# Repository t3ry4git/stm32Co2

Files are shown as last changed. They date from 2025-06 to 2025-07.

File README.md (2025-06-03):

# stm32Co2

A simple CO2 and environmental monitor based on the STM32F103C8 microcontroller. The firmware reads temperature and humidity from a DHT22 sensor, measures CO2 concentration using an MHZ19B module and displays values on an SSD1306 OLED screen.

## Hardware requirements

- **MCU:** STM32F103C8 ("Blue Pill" or compatible)
- **Temperature/Humidity sensor:** DHT22
- **CO2 sensor:** MHZ19B (UART interface)
- **Display:** SSD1306 I2C OLED

## Building with STM32CubeIDE

1. Open the `test.ioc` project file in STM32CubeIDE.
2. Let CubeIDE generate the project files if prompted.
3. Build the `test` target from the IDE. Default settings produce both `Debug` and `Release` outputs.
4. Flash the resulting binary to your board using the built‑in CubeIDE programmer or an external tool such as ST‑Link.

## Third‑party software

This repository includes STM32 HAL drivers from STMicroelectronics under the BSD‑3‑Clause license as found in `Drivers/STM32F1xx_HAL_Driver/LICENSE.txt`. The SSD1306 display driver and font code in `Core/Src` and `Core/Inc` are distributed under the GNU GPL version 3.

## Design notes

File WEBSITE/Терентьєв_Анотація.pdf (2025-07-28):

2

АНОТАЦІЯ
Кваліфікаційна робота включає пояснювальну записку (65- с., 24 - рис. 2 -

табл., 3- додатки).

У роботі розроблено портативну систему для моніторингу температури,

відносної вологості та концентрації вуглекислого газу у повітрі закритих

приміщень. Апаратна частина побудована на мікроконтролері STM32F103C8T6

з підключенням цифрових сенсорів DHT22 та MH-Z19B. Перший забезпечує

вимірювання температури й вологості, другий — контроль рівня вуглекислого

газу на основі недисперсної інфрачервоної технології (NDIR).

У процесі реалізації:

― | Проведено аналіз існуючих технічних рішень у сфері локального моніторингу повітряного середовища;
― | Визначено вимоги до портативної системи з урахуванням умов експлуатації;
― | Розроблено принципову електричну схему пристрою та підібрано відповідні компоненти;
― | Реалізовано прошивку для мікроконтролера з функціями зчитування, обробки та виведення даних на графічний дисплей.

Розроблена система характеризується низьким енергоспоживанням,

компактними розмірами та може функціонувати автономно від стаціонарних

джерел живлення. Такий пристрій є доцільним для застосування у житлових,

навчальних, офісних або лабораторних приміщеннях, де необхідно контролювати

стан повітряного середовища.

Ключові слова: STM32, MH-Z19B, DHT22, моніторинг, CO2, температура,

вологість, NDIR, портативна система, мікроконтролер.

3

ABSTRACT

The qualification work includes an explanatory note (65 p.,24 figures,2 tables,3

appendices).

This work presents the development of a portable system for monitoring

temperature, relative humidity, and carbon dioxide concentration in indoor

environments. The hardware is based on the STM32F103C8T6 microcontroller, with

connected digital sensors DHT22 and MH-Z19B. The DHT22 measures temperature

and humidity, while the MH-Z19B provides carbon dioxide concentration data using

non-dispersive infrared (NDIR) technology.

During the development process:

― | Existing technical solutions for local air quality monitoring were analyzed;
― | System requirements were defined according to operating conditions;
― | A circuit diagram was developed and appropriate components selected;
― | Firmware was implemented to enable data acquisition, processing, and display on a graphical screen.

The system is characterized by low power consumption, compact dimensions,

and the ability to operate independently of stationary power sources. It is suitable for

use in residential, educational, office, or laboratory environments where air quality

monitoring is required.

Keywords: STM32, MH-Z19B, DHT22, monitoring, CO2, temperature,

humidity, NDIR, portable system, microcontroller.

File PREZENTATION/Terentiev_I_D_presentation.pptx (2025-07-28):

## Портативна система моніторингу концентрації CO2 з графічним інтерфейсом

Виконав: студент IV курсу, групи КВ-11
Терентьєв Іван Дмитрович
Керівник: доц.каф. СПіСКС, к.т.н.
Щербина Олександр Андрійович

## Актуальність

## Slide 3

Погіршення якості повітря у приміщеннях

Згідно з дослідженнями, підвищений рівень CO₂ безпосередньо впливає на працездатність, викликає втому, сонливість та знижує концентрацію. У більшості житлових і робочих приміщень відсутні засоби моніторингу цього параметра.

Недоступність ефективних автономних рішень

Існуючі пристрої для контролю мікроклімату здебільшого дорогі, потребують постійного живлення або мають складну структуру налаштувань, що обмежує їх використання у побуті чи в умовах обмежених ресурсів.

Потреба у мобільних та енергоефективних системах

Більшість доступних рішень або складні в користуванні, або прив’язані до хмарних сервісів. Це унеможливлює їх застосування у простих побутових умовах, де потрібна швидка та надійна індикація якості повітря.

## Мета

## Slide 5

Забезпечити контроль якості повітря у приміщеннях. Розробити портативний пристрій для моніторингу CO₂, температури та вологості, що допоможе оперативно реагувати на зміни мікроклімату.
Підвищити комфорт і продуктивність. Створити технічне рішення, що сприятиме кращому самопочуттю людей у навчальних, житлових і робочих просторах.
Реалізувати автономну систему. Забезпечити енергонезалежність пристрою за допомогою живлення від акумулятора та оптимального енергоспоживання.
Використати сучасну елементну базу. Застосувати мікроконтролер STM32 та цифрові сенсори для точних і стабільних вимірювань без потреби в складному обслуговуванні.

## Огляд існуючих рішень

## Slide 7

Смарт-термостати

Google Nest, Tado — керують опаленням, збирають дані про температуру, вологість і рух. Вимагають підключення до Wi-Fi.

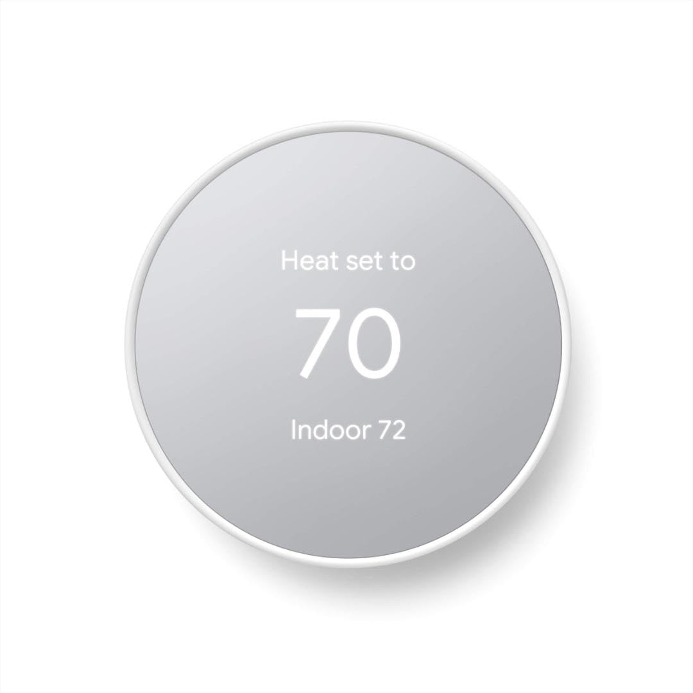
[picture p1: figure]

Компактні метеостанції

Netatmo, Xiaomi Mi Monitor — вимірюють базові параметри (температура, вологість), мають E-Ink дисплеї, працюють на батарейках.

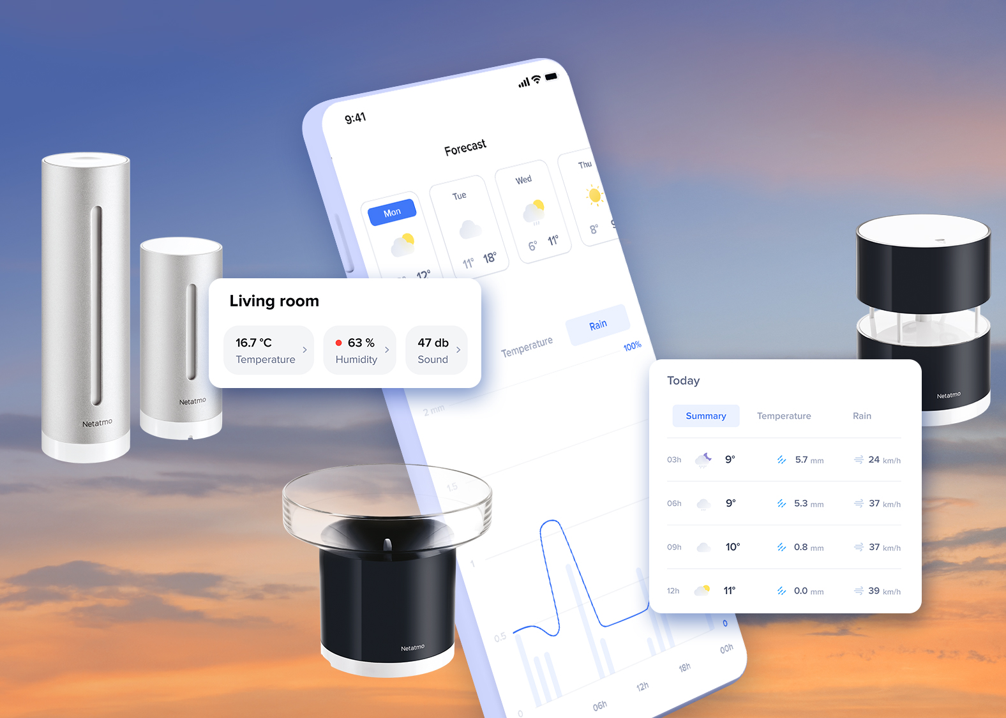
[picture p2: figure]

Системи безпеки з кліматичним моніторингом

Ajax LifeQuality — поєднують CO₂-датчики з охоронними функціями. Працюють у складі фірмової екосистеми.

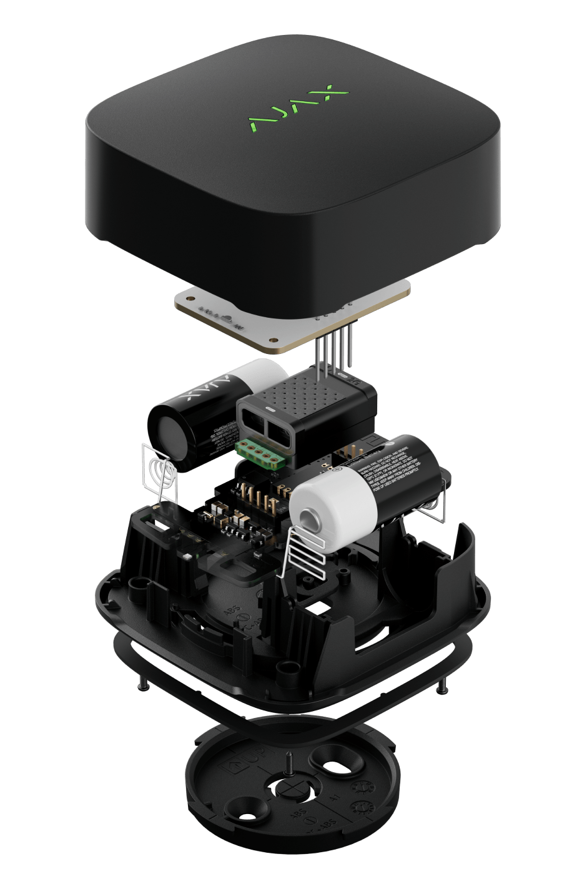
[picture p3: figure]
Ajax LifeQuality is a smart air quality monitor

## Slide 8

Професійні вимірювачі

Testo, ELT Sensor — призначені для лабораторій. Забезпечують точні вимірювання CO₂, TVOC, температури. Дорогі, потребують калібрування.

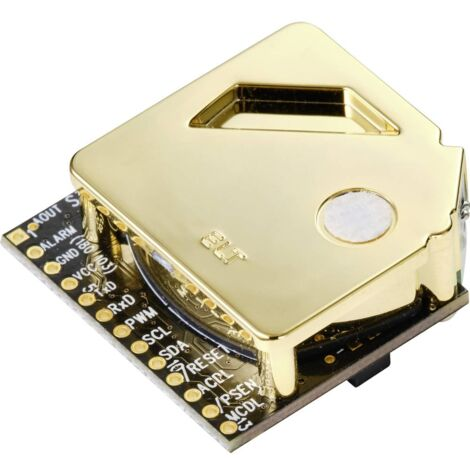
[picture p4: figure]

DIY-рішення загального призначення

Конструкції на базі Arduino, ESP або STM32. Підходять для ентузіастів, гнучкі, але потребують знань у схемотехніці та програмуванні.

Системи з інтегрованим моніторингом

Dyson, Mitsubishi Electric — мають вбудовані сенсори повітря в системах вентиляції або кондиціювання. Висока ціна, обмежена модифікація.

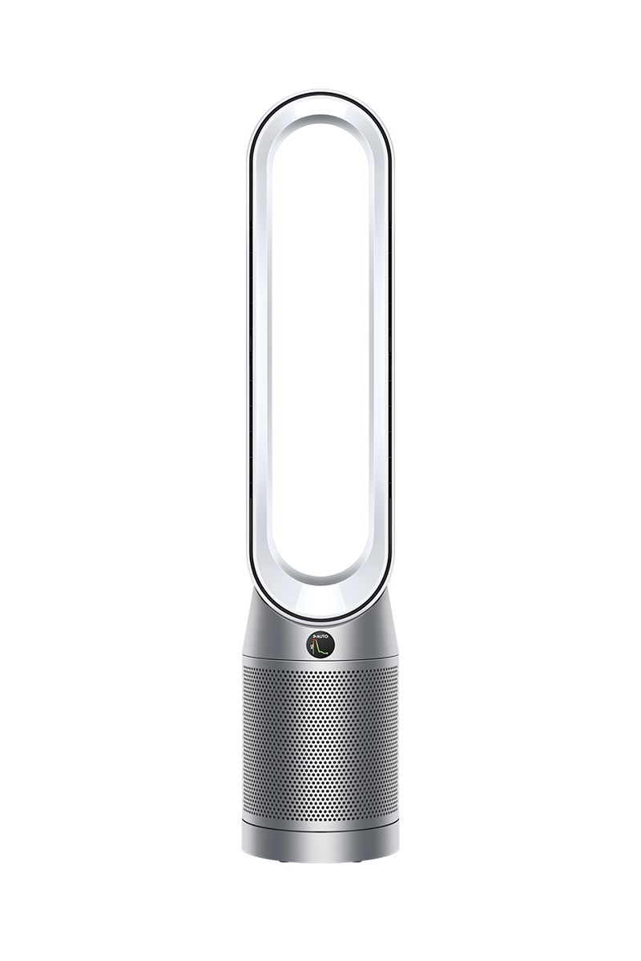
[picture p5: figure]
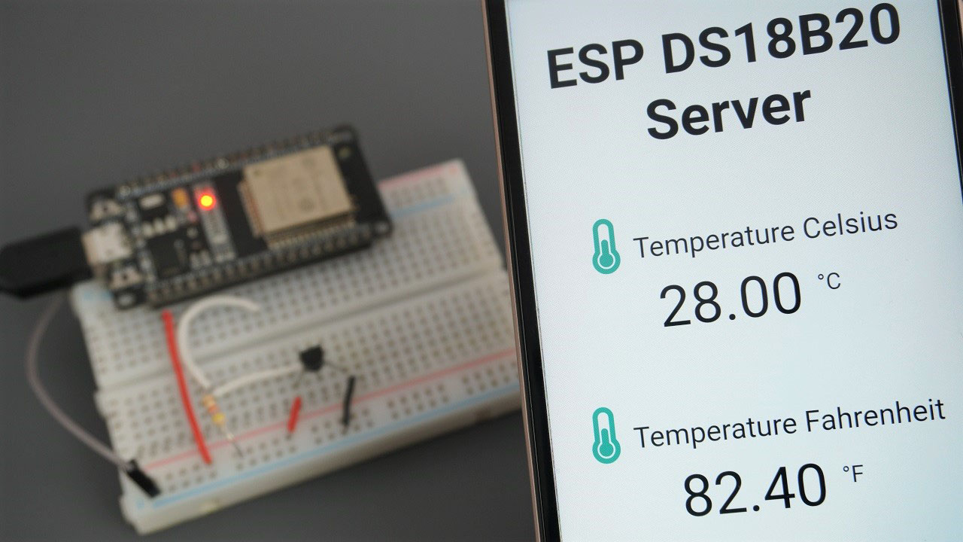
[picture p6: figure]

## Обрані технології

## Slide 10

Мікроконтролер

Датчики

Індикація

STM32F103C8T6

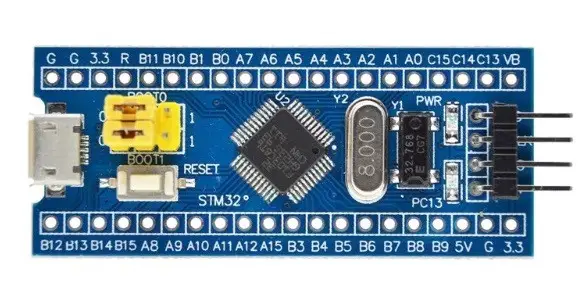
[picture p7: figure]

DHT22 та MH-Z19B

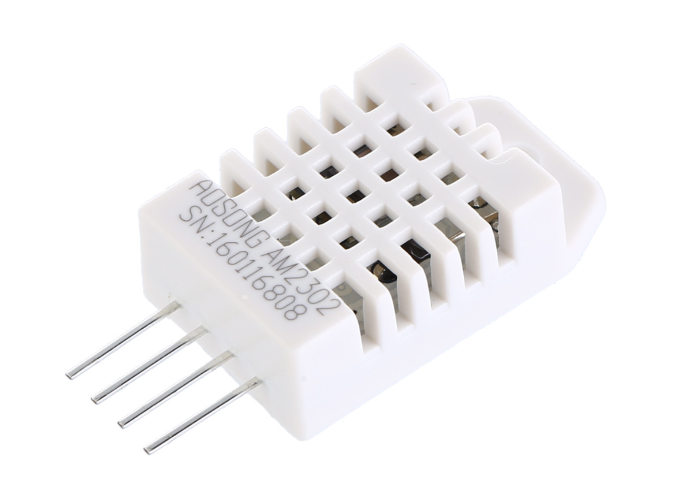
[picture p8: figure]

OLED-дисплей SSD1306

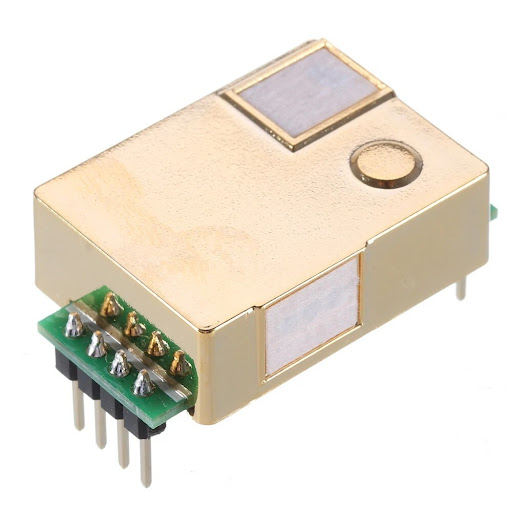
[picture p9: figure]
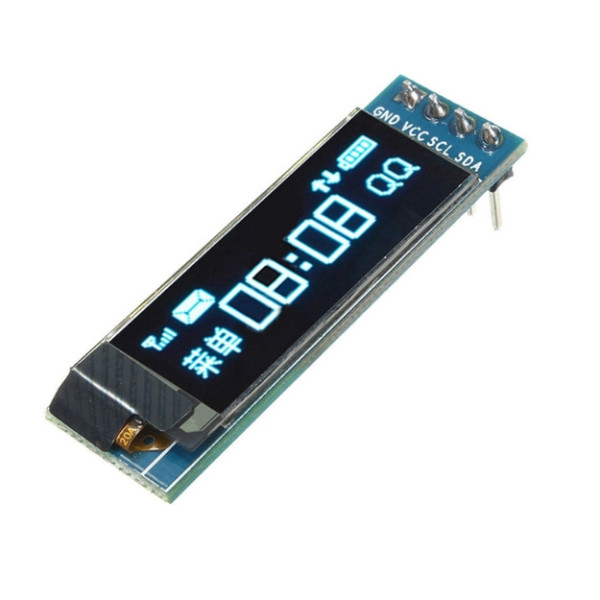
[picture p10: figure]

Живлення та керування зарядом

TP4056, MT3608 та AP2112K

Програмне забезпечення

STM32CubeMX
STM32CubeIDE
STM32CubeProgrammer

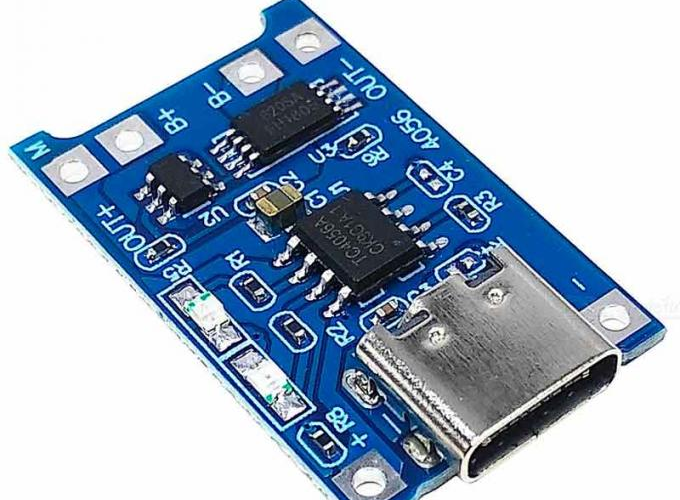
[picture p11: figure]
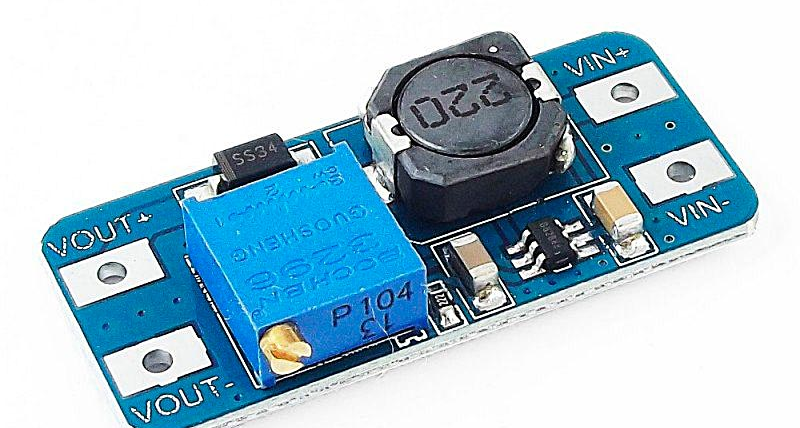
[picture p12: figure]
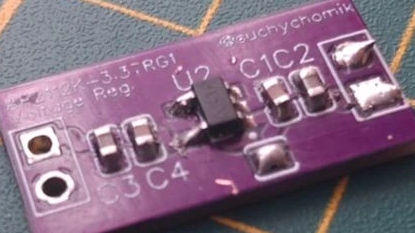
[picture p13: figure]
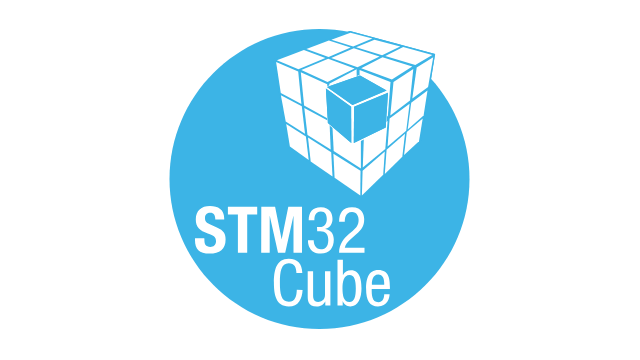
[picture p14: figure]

## Результати розробки пристрою

## Загальна електрична схема пристрою

Основні компоненти

Мікроконтролер STM32F103C8T6 — ядро системи, обробка даних, керування
Сенсори:
MH-Z19B — вимірювання CO₂ (UART)
DHT22 — температура та вологість (цифровий пін)
Дисплей OLED SSD1306 — графічна індикація (I²C)
Кнопка калібрування — ручне оновлення базового рівня CO₂

Живлення

Li-Ion акумулятори 2×18650 (паралельно)
TP4056 — зарядка акумуляторів через microUSB
MT3608 — підвищення напруги до 5В для живлення логіки
AP2112K — стабілізація живлення для дисплея та сенсорів

Інтерфейси

UART — зв'язок з MH-Z19B
I²C — дисплей SSD1306

## Загальна електрична схема пристрою. Додаток А. Схема електрична принципова

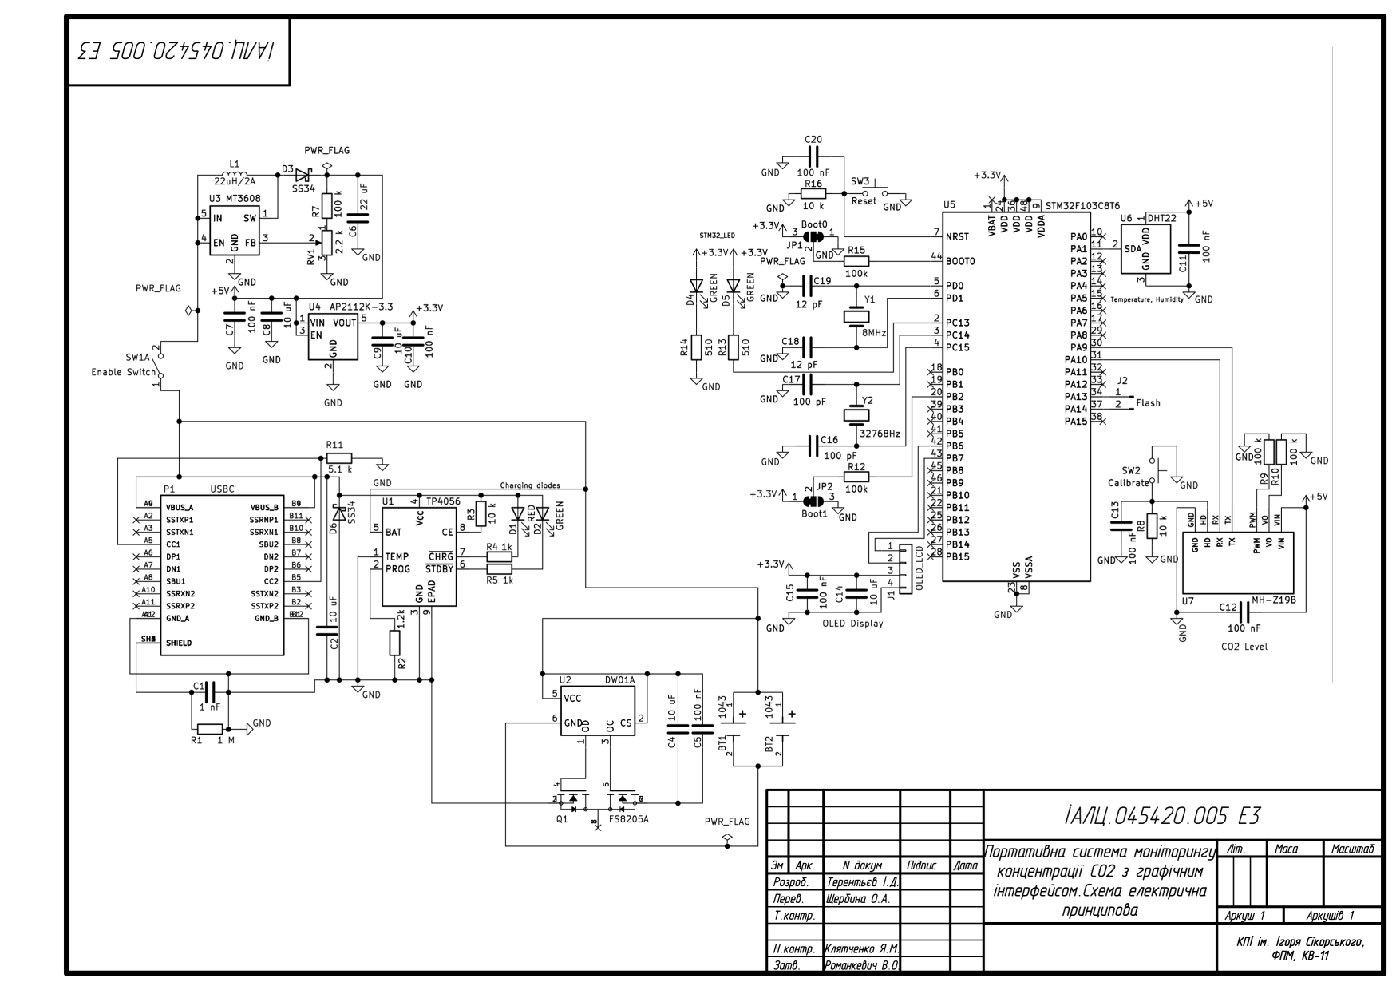
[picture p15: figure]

## Розробка друкованої плати

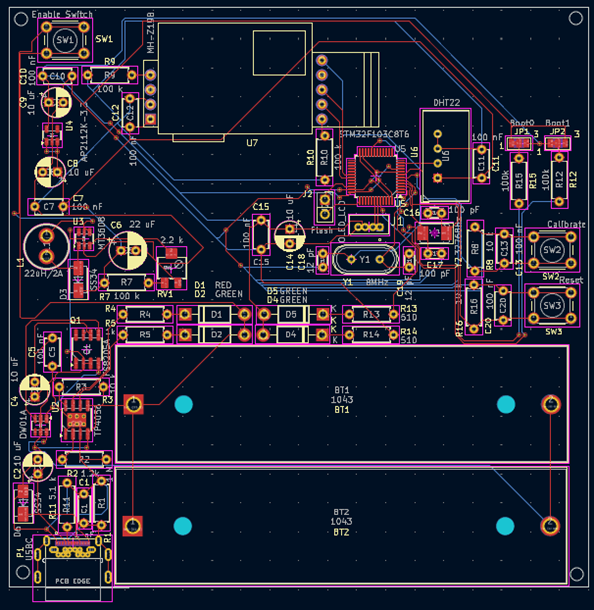
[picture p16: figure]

Габарити

100х100 мм, двустороння

Принципи розміщення

- Живлення зліва, логіка — по центру
- Сенсори — на периферії для відкритого доступу
- Кнопки винесені для взаємодії з користувачем
- Мінімізація перехресних трас і шумів

## Розробка друкованої плати

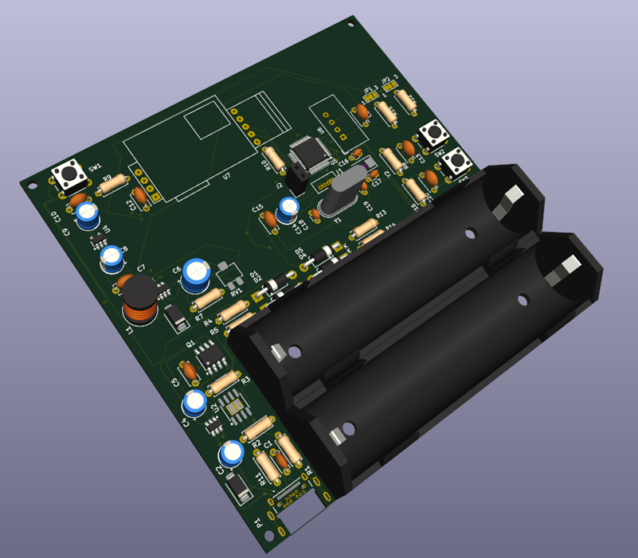
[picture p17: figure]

Перевірка компонування

- Усі компоненти вміщено в допустимий об’єм корпусу
- 3D-візуалізація допомогла виявити конфлікти між конекторами та елементами
- Правильна орієнтація компонентів для пайки та монтажу

## Програмна реалізація

Основні етапи

- Ініціалізація мікроконтролера, периферії, дисплея
- Обробка сенсорів DHT22 та MH-Z19B
- Перевірка помилок і прогріву
- Виведення даних на дисплей
- Періодичне оновлення інформації

Особливості

- Реакція на збої сенсорів через інформування користувача
- Калібрування CO₂ вручну кнопкою
- Таймер для прогріву датчика MH-Z19B перед зчитуванням
- Мінімізація навантаження через прапорець оновлення дисплея

## Програмна реалізація. Додаток Б. Структура алгоритму роботи мікропрограми

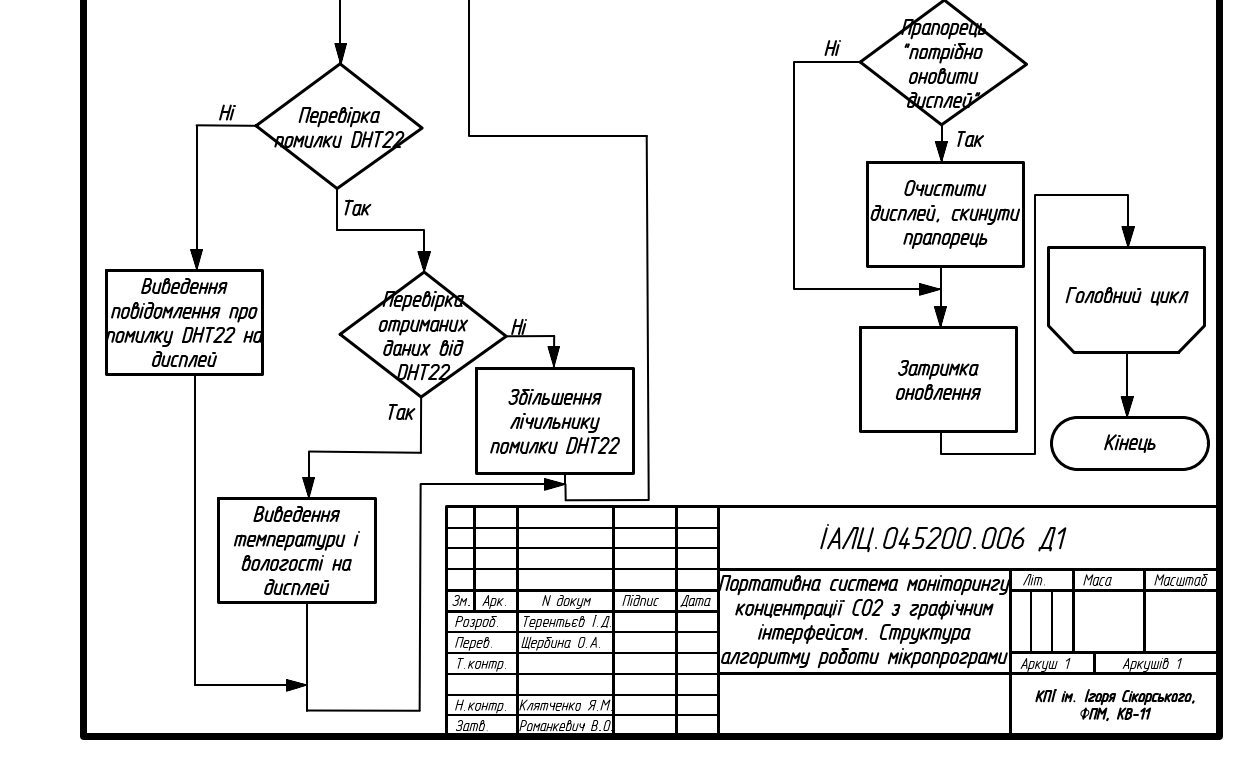
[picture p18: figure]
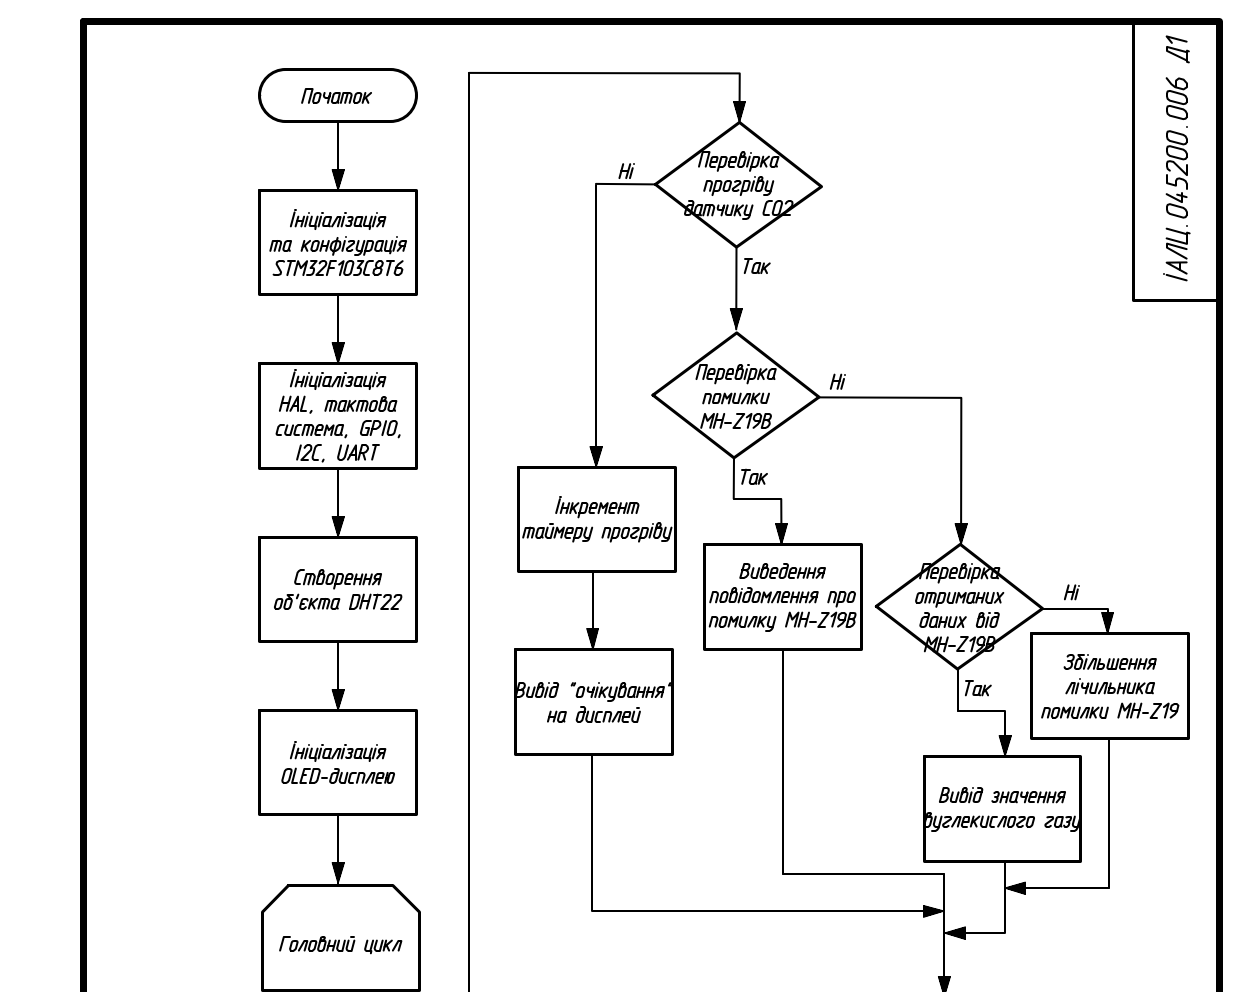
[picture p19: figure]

## Висновок

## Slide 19

- Розроблено автономний пристрій на базі STM32F103 для локального моніторингу рівня CO₂, температури та вологості в приміщеннях. Він призначений для покращення умов перебування людей та контролю мікроклімату без підключення до мережі.
- Система використовує цифрові сенсори DHT22 та MH-Z19B, що забезпечують точні вимірювання. Результати виводяться на OLED-дисплей, що дозволяє швидко оцінити стан повітря без додаткових пристроїв.
- Пристрій живиться від акумулятора з керуванням зарядом через модулі TP4056 та MT3608, що забезпечує автономність і можливість роботи в мобільних умовах.
- Завдяки низькій собівартості, простоті конструкції та відсутності залежності від інтернет-зв’язку, система може бути використана у школах, офісах, житлових приміщеннях, тимчасових спорудах або як DIY-рішення для ентузіастів.

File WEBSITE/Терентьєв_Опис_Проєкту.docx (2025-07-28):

У межах бакалаврського дипломного проєкту було розроблено портативний мікропроцесорний пристрій для моніторингу параметрів мікроклімату в закритих приміщеннях, зокрема концентрації вуглекислого газу, температури та відносної вологості повітря. Основна мета пристрою — забезпечення локального контролю якості повітря без підключення до зовнішніх систем чи мереж. Сучасні житлові й офісні простори часто характеризуються обмеженим повітрообміном, що призводить до поступового накопичення CO₂. Перевищення допустимих концентрацій негативно впливає на самопочуття, викликає втому, зниження концентрації та головний біль, тому наявність інформативного й автономного засобу контролю цих параметрів є важливим як у побутовому, так і в навчальному чи професійному середовищі.

Апаратною основою розробки є 32-бітний мікроконтролер STM32F103C8T6 з архітектурою ARM Cortex-M3, який відповідає за опитування сенсорів, обробку даних та керування виведенням інформації на дисплей. Для вимірювання концентрації CO₂ використано сенсор MH-Z19B, що працює за недисперсійним інфрачервоним принципом і сполучається з контролером через UART-інтерфейс. Діапазон вимірювання охоплює значення до 5000 ppm, а наявність автоматичного калібрування дозволяє забезпечити стабільну точність без втручання користувача. Температура та вологість фіксуються сенсором DHT22, який передає дані через однодротовий протокол. Обидва сенсори мають низький рівень енергоспоживання, що важливо для забезпечення тривалої автономної роботи пристрою.

Для виведення даних використано монохромний OLED-дисплей SSD1306 з роздільною здатністю 128×64 пікселі, який працює через інтерфейс I²C. Виведення значень реалізовано у зручному для сприйняття вигляді. Завдяки використанню OLED-технології досягається висока контрастність і добрий рівень зчитуваності при різному освітленні.

Живлення пристрою реалізоване на основі акумулятора формату 18650, що заряджається через модуль TP4056 із захистом від перезаряду та глибокого розряду. Для забезпечення стабільної напруги живлення використано комбінацію підвищуючого перетворювача MT3608 та стабілізатора напруги AP2112K на 3.3 В. Така конфігурація дозволила створити повністю автономну систему, здатну працювати впродовж тривалого часу без потреби у зовнішньому живленні, що робить пристрій зручним для мобільного застосування.

Всі компоненти змонтовано на друкованій платі, спроєктованій за допомогою середовища KiCAD. При трасуванні враховано оптимізацію шляхів сигналів, мінімізацію перешкод та захист логіки керування. Особливу увагу приділено компактності плати та зручності подальшого монтажу у корпус. Конструкція передбачає окремі роз’єми для зарядки акумулятора, підключення дисплею та датчику температури і вологості.

Програмне забезпечення пристрою реалізовано мовою C з використанням бібліотек STM32 HAL. Робота програми базується на безперервному циклі з опитуванням сенсорів, аналізом отриманих значень та виведенням їх на дисплей. Для роботи з екраном використано сторонню бібліотеку, розповсюджену за ліцензією GPLv3, адаптовану для використання з мікроконтролерами серії STM32F1. Програмна логіка передбачає обробку контрольної суми відповіді від MH-Z19B, контроль затримки для DHT22, а також можливість ручного або автоматичного калібрування сенсорів у разі необхідності. Реалізовано також систему повідомлень про помилки сенсорів з відповідними повідомленнями на дисплеї.

Результатом проєкту є повнофункціональний автономний пристрій, здатний оперативно вимірювати ключові параметри мікроклімату та наочно відображати їх без залучення смартфонів чи зовнішніх серверів. Такий підхід дозволяє забезпечити більшу надійність, незалежність від мережі та простоту використання. Система може бути застосована як у побуті — наприклад, для контролю повітря в дитячих кімнатах чи спальнях, — так і в навчальних або офісних приміщеннях, де важливо вчасно виявити надлишкову концентрацію CO₂ та вжити заходів з провітрювання. Пристрій може слугувати платформою для подальших розробок, зокрема — інтеграції бездротового зв’язку, додавання картки пам’яті для логування історії або розширення спектру вимірюваних параметрів, таких як атмосферний тиск чи рівень освітлення.

Таким чином, проєкт об’єднує у собі практичну цінність, технологічну завершеність і потенціал до масштабування, що дозволяє розглядати його як повноцінну навчально-прикладну розробку, актуальну для реальних сценаріїв використання.

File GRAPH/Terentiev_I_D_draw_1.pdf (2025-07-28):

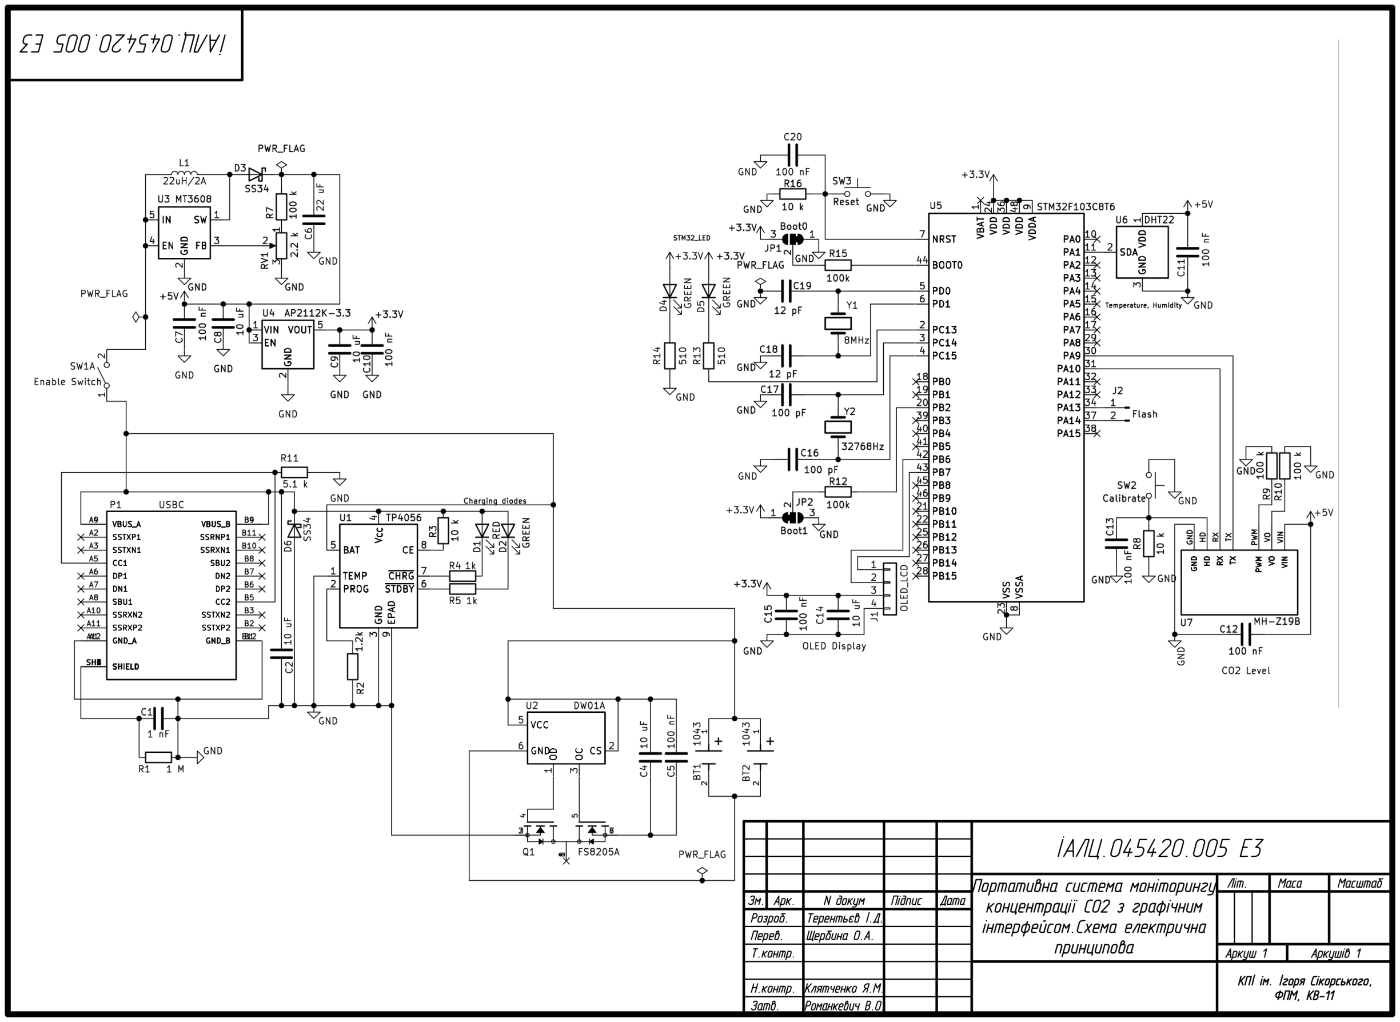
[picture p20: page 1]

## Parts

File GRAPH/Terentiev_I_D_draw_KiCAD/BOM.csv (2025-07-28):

Reference | Value | Footprint | Datasheet | Qty | DNP | Exclude from BOM | Exclude from Board
BT1,BT2 | 1043 | Battery:BatteryHolder_MPD_BH-18650-PC2 |  | 2
C1 | 1 nF | Capacitor_THT:C_Disc_D4.3mm_W1.9mm_P5.00mm | ~ | 1
C2,C4,C8,C9,C14 | 10 uF | Capacitor_THT:CP_Radial_D5.0mm_P2.50mm | ~ | 5
C5,C7,C10,C11,C12,C13,C15,C20 | 100 nF | Capacitor_THT:C_Disc_D4.7mm_W2.5mm_P5.00mm | ~ | 8
C6 | 22 uF | Capacitor_THT:CP_Radial_D6.3mm_P2.50mm | ~ | 1
C16,C17 | 100 pF | Capacitor_THT:C_Disc_D3.0mm_W1.6mm_P2.50mm | ~ | 2
C18,C19 | 12 pF | Capacitor_THT:C_Disc_D3.0mm_W1.6mm_P2.50mm | ~ | 2
D1 | RED | Diode_THT:D_DO-41_SOD81_P10.16mm_Horizontal | ~ | 1
D2,D4,D5 | GREEN | Diode_THT:D_DO-41_SOD81_P10.16mm_Horizontal | ~ | 3
D3,D6 | SS34 | Diode_SMD:D_SMA | https://www.vishay.com/docs/88751/ss32.pdf | 2
J1 | OLED_LCD | MountingEquipment:TE_1734598-4 | ~ | 1
J2 | Flash | Connector_PinSocket_2.54mm:PinSocket_1x02_P2.54mm_Vertical | ~ | 1
JP1 | Boot0 | Jumper:SolderJumper-3_P1.3mm_Bridged12_Pad1.0x1.5mm_NumberLabels | ~ | 1 |  | Excluded from BOM
JP2 | Boot1 | Jumper:SolderJumper-3_P1.3mm_Bridged12_Pad1.0x1.5mm_NumberLabels | ~ | 1 |  | Excluded from BOM
L1 | 22uH/2A | Inductor_THT:L_Radial_D7.5mm_P3.50mm_Fastron_07P | ~ | 1
P1 | USBC | Connector:usbc |  | 1
Q1 | FS8205A | Package_SO:SOIC-8_3.9x4.9mm_P1.27mm |  | 1
R1 | 1 M | Resistor_THT:R_Axial_DIN0207_L6.3mm_D2.5mm_P7.62mm_Horizontal | ~ | 1
R2 | 1.2k | Resistor_THT:R_Axial_DIN0207_L6.3mm_D2.5mm_P7.62mm_Horizontal | ~ | 1
R3,R8,R16 | 10 k | Resistor_THT:R_Axial_DIN0207_L6.3mm_D2.5mm_P7.62mm_Horizontal | ~ | 3
R4,R5 | 1k | Resistor_THT:R_Axial_DIN0207_L6.3mm_D2.5mm_P7.62mm_Horizontal | ~ | 2
R7,R9,R10 | 100 k | Resistor_THT:R_Axial_DIN0207_L6.3mm_D2.5mm_P7.62mm_Horizontal | ~ | 3
R11 | 5.1 k | Resistor_THT:R_Axial_DIN0207_L6.3mm_D2.5mm_P7.62mm_Horizontal | ~ | 1
R12,R15 | 100k | Resistor_THT:R_Axial_DIN0207_L6.3mm_D2.5mm_P7.62mm_Horizontal | ~ | 2
R13,R14 | 510 | Resistor_THT:R_Axial_DIN0207_L6.3mm_D2.5mm_P7.62mm_Horizontal | ~ | 2
RV1 | 2.2 k | Potentiometer_SMD:Potentiometer_Bourns_3214X_Vertical | ~ | 1
SW1 | Enable Switch | Button_Switch_THT:SW_PUSH_6mm | ~ | 1
SW2 | Calibrate | Button_Switch_THT:SW_PUSH_6mm | ~ | 1
SW3 | Reset | Button_Switch_THT:SW_PUSH_6mm | ~ | 1
U1 | TP4056 | Package_SO:SOIC-8-1EP_3.9x4.9mm_P1.27mm_EP2.41x3.3mm_ThermalVias | https://www.lcsc.com/datasheet/lcsc_datasheet_2410121619_TOPPOWER-Nanjing-Extension-Microelectronics-TP4056-42-ESOP8_C16581.pdf | 1
U2 | DW01A | Package_TO_SOT_SMD:SOT-23-6 | https://hmsemi.com/downfile/DW01A.PDF | 1
U3 | MT3608 | Package_TO_SOT_SMD:SOT-23-6 | https://www.olimex.com/Products/Breadboarding/BB-PWR-3608/resources/MT3608.pdf | 1
U4 | AP2112K-3.3 | Package_TO_SOT_SMD:SOT-23-5 | https://www.diodes.com/assets/Datasheets/AP2112.pdf | 1
U5 | STM32F103C8T6 | Package_QFP:LQFP-48_7x7mm_P0.5mm | https://www.st.com/resource/en/datasheet/stm32f103c8.pdf | 1
U6 | DHT22 | Sensor:ASAIR_AM2302_P2.54mm_Vertical | http://akizukidenshi.com/download/ds/aosong/AM2302.pdf | 1
U7 | MH-Z19B | Sensor:MH-Z19B |  | 1
Y1 | 8MHz | Crystal:Crystal_HC49-U_Vertical | ~ | 1
Y2 | 32768Hz | Crystal:Crystal_SMD_Abracon_ABM3-2Pin_5.0x3.2mm | ~ | 1

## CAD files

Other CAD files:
GRAPH/Terentiev_I_D_draw.dwg

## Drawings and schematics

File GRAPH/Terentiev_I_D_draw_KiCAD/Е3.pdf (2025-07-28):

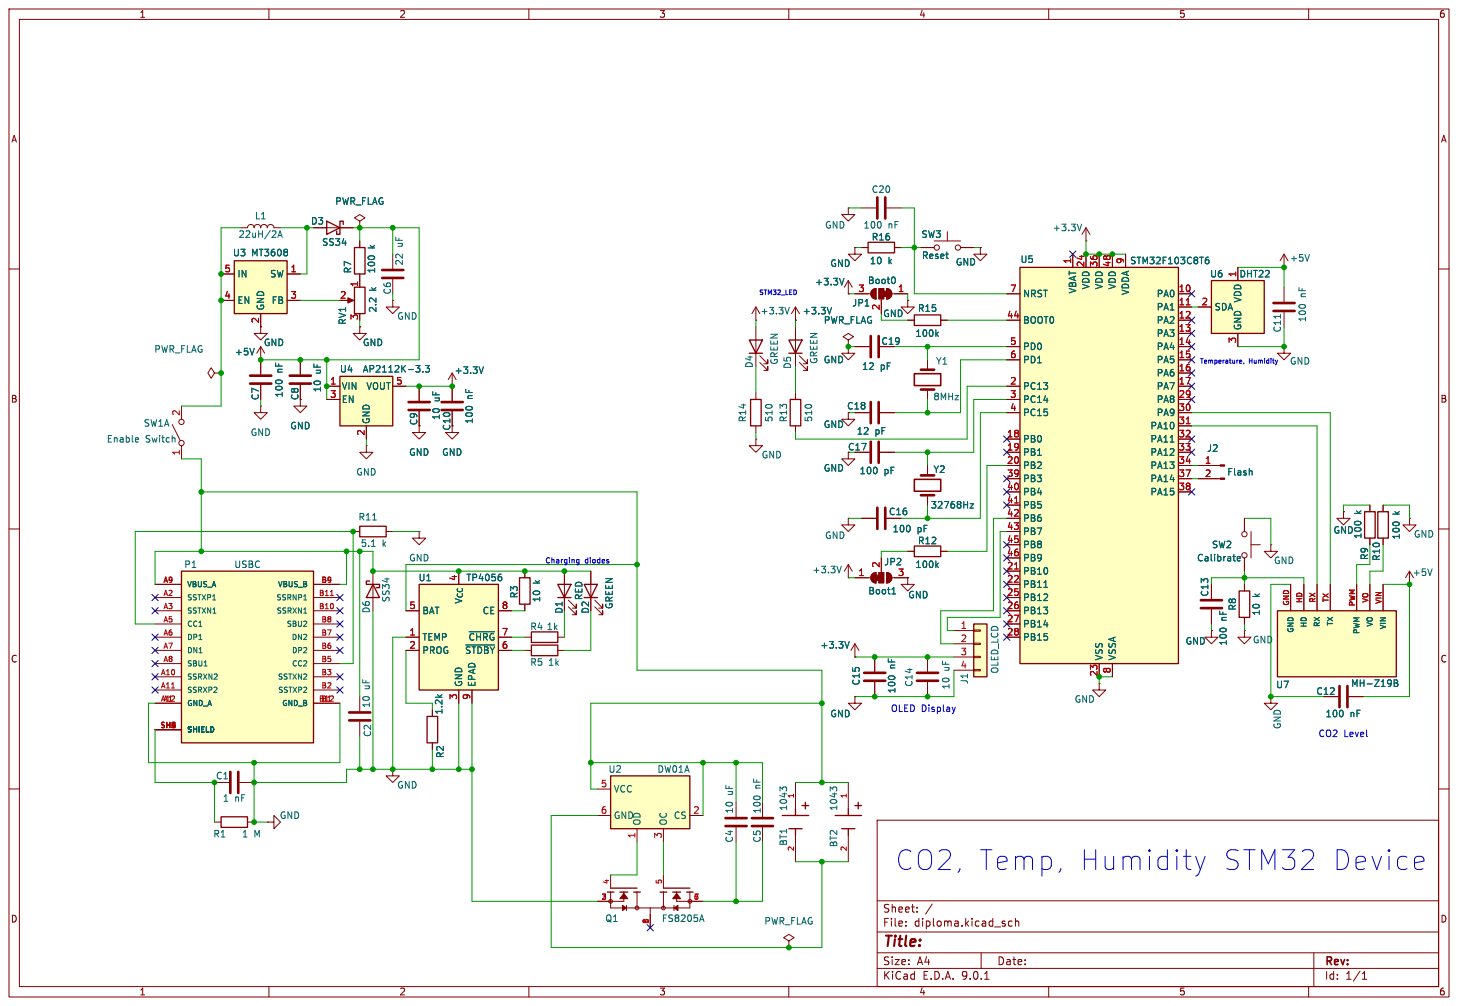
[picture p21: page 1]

9 PA0 10 PA1 11 PA2 12 PA3 13 PA4 14 PA5 15 PA6 16 PA7 17 PA8 29 PA9 30 PA10 31 PA11 32 PA12 33 PA13 34 PA14 37 PA15 38 U5 STM32F103C8T6 GND C2 10 uF GND GND R8 10 k R15

1 VDD 24 VDD 36 VSS 23 VDD 48 VSSA

2 SW 1 FB 3 C10100 nF U4 AP2112K-3.3 VIN 1 EN 3 GND

3 BAT 5 TEMP 1 PROG 2 U1 TP4056 C810 uF C1

2 VOUT 5 U4 AP2112K-3.3 VIN VIN VO VO PWM PWM TX TX RX RX HD HD GND GND U7 MH-Z19B R11

3 BAT 5 TEMP 1 PROG 2 R3 10 k D1 RED D2GREEN

Id: 1/1 Title: File: diploma.kicad_sch Sheet: /

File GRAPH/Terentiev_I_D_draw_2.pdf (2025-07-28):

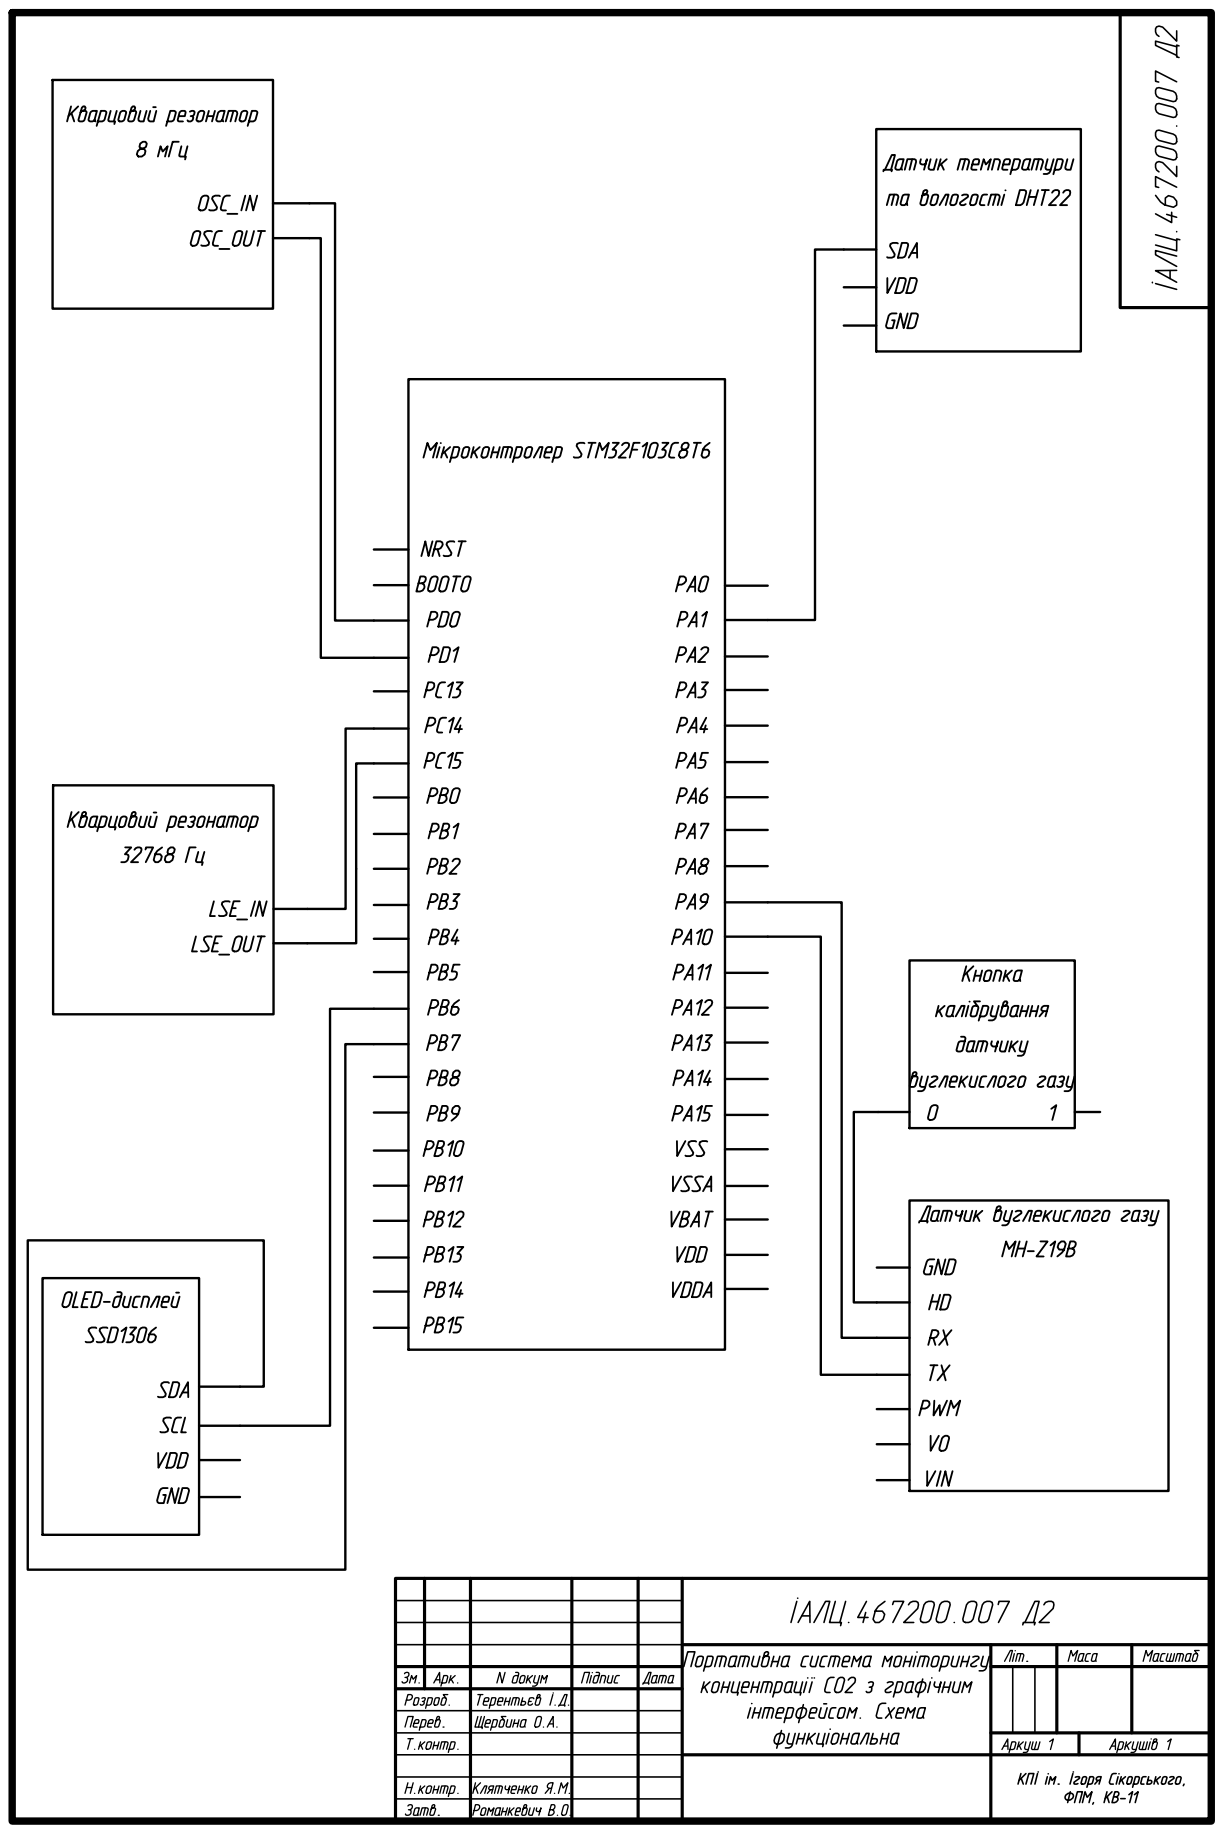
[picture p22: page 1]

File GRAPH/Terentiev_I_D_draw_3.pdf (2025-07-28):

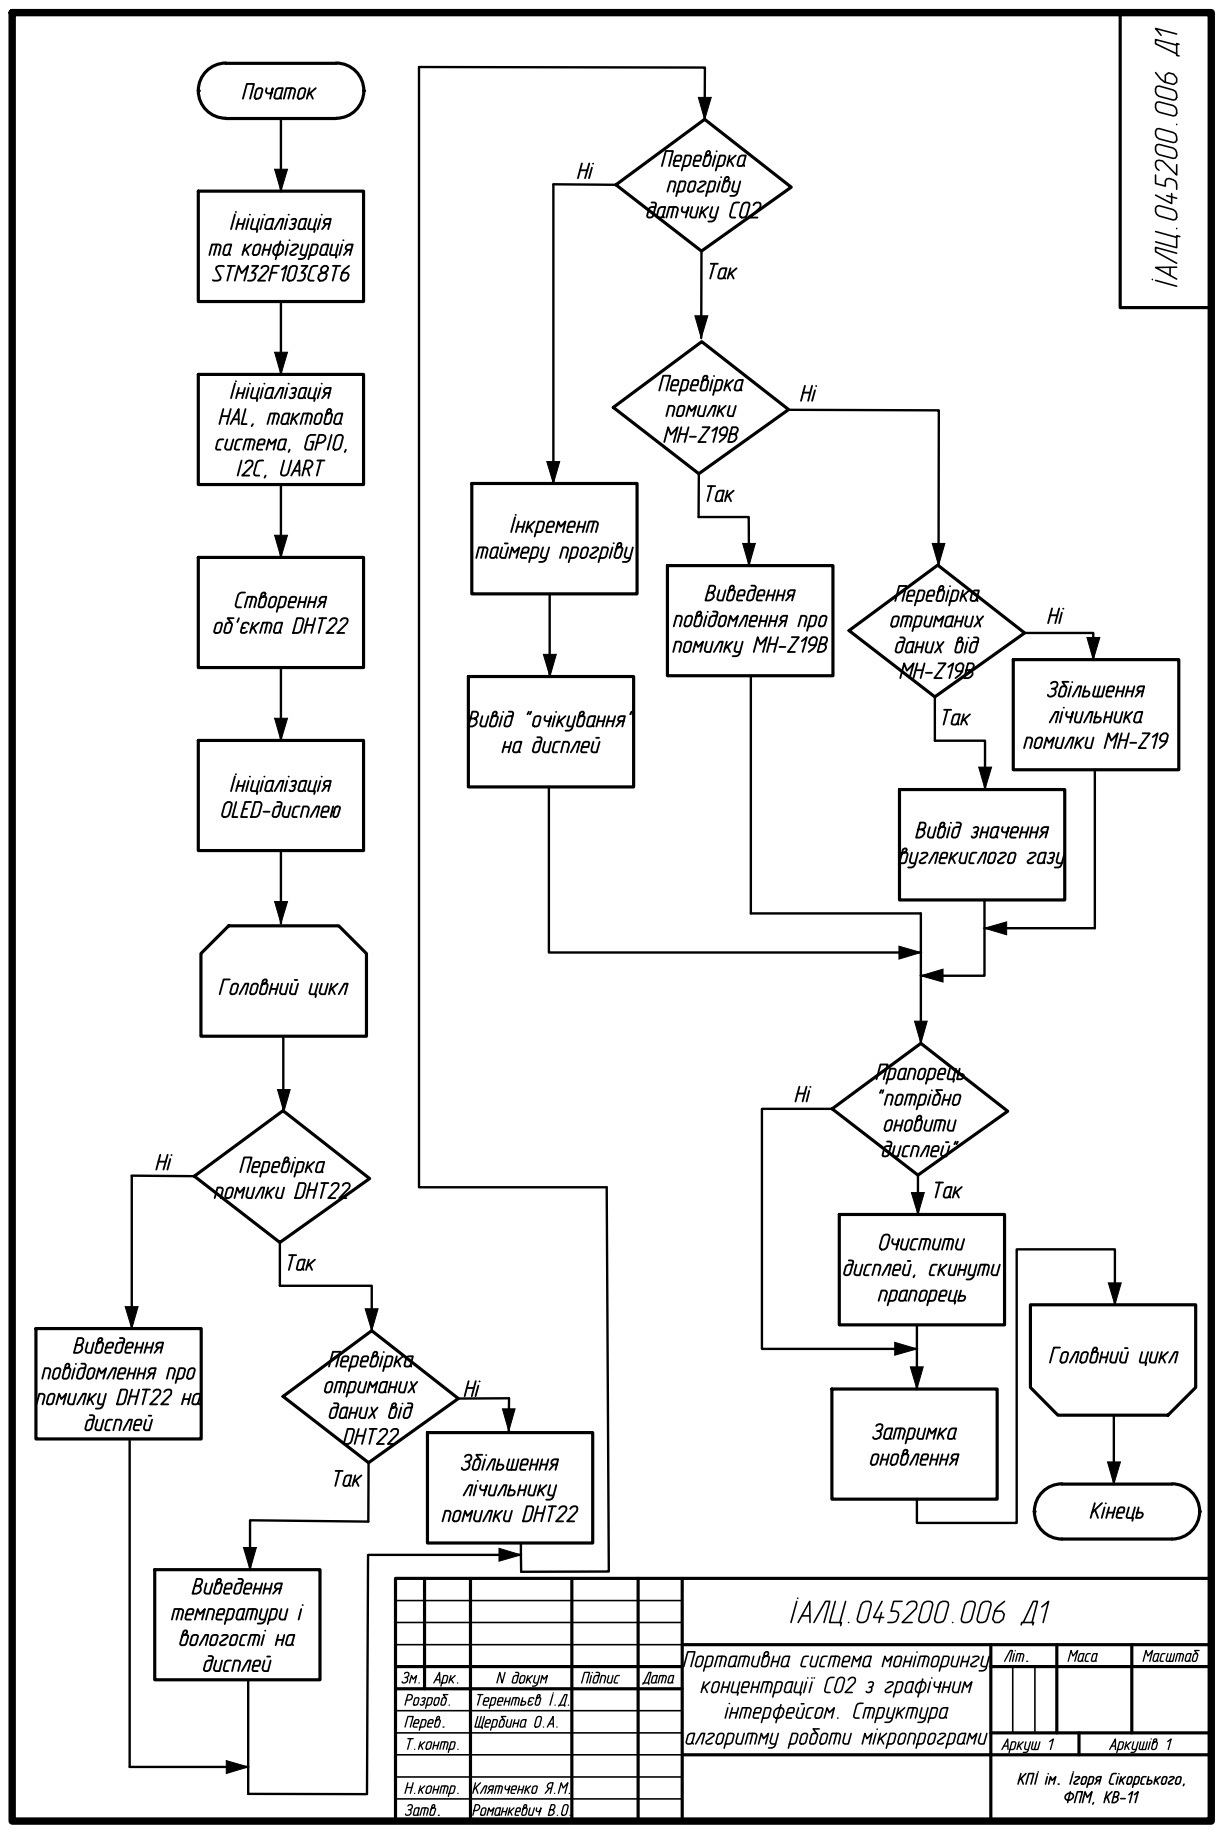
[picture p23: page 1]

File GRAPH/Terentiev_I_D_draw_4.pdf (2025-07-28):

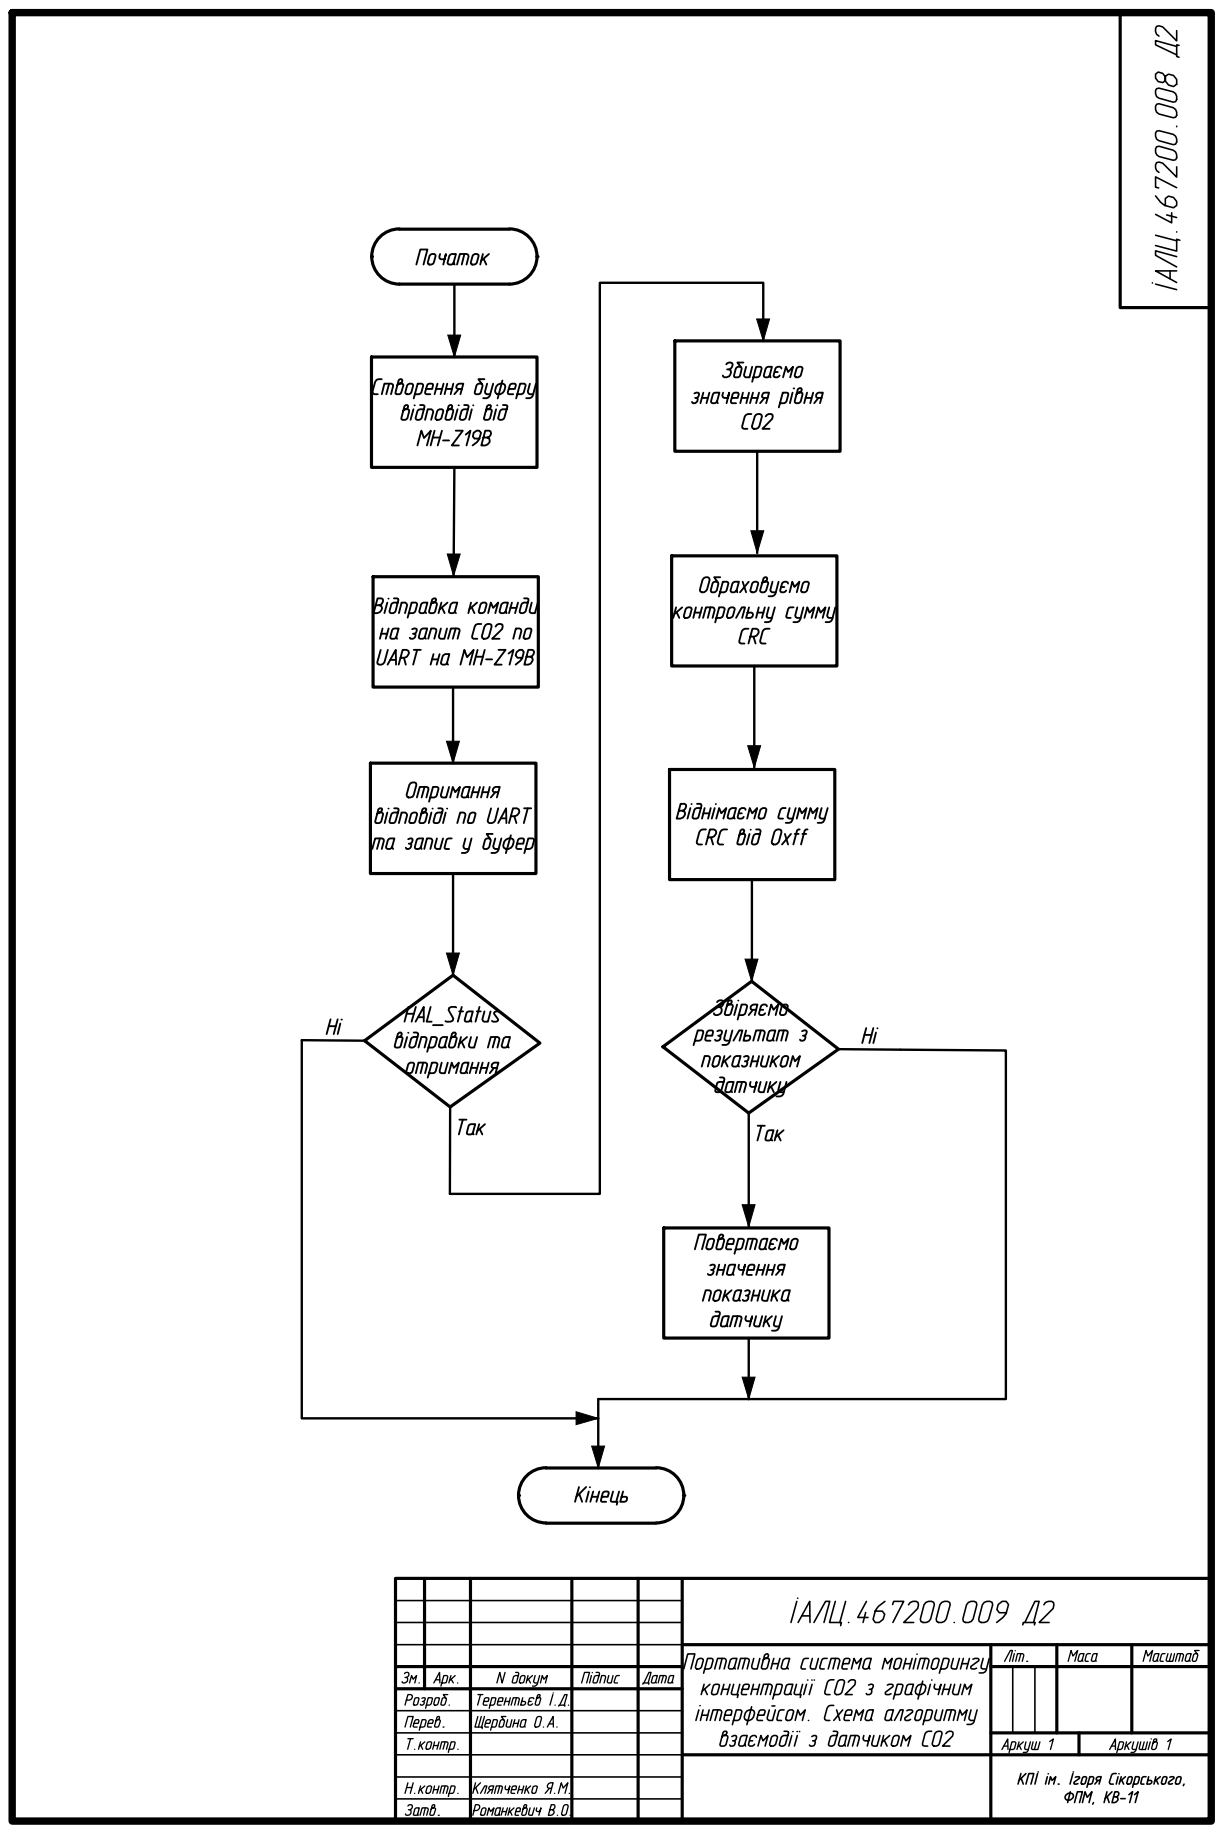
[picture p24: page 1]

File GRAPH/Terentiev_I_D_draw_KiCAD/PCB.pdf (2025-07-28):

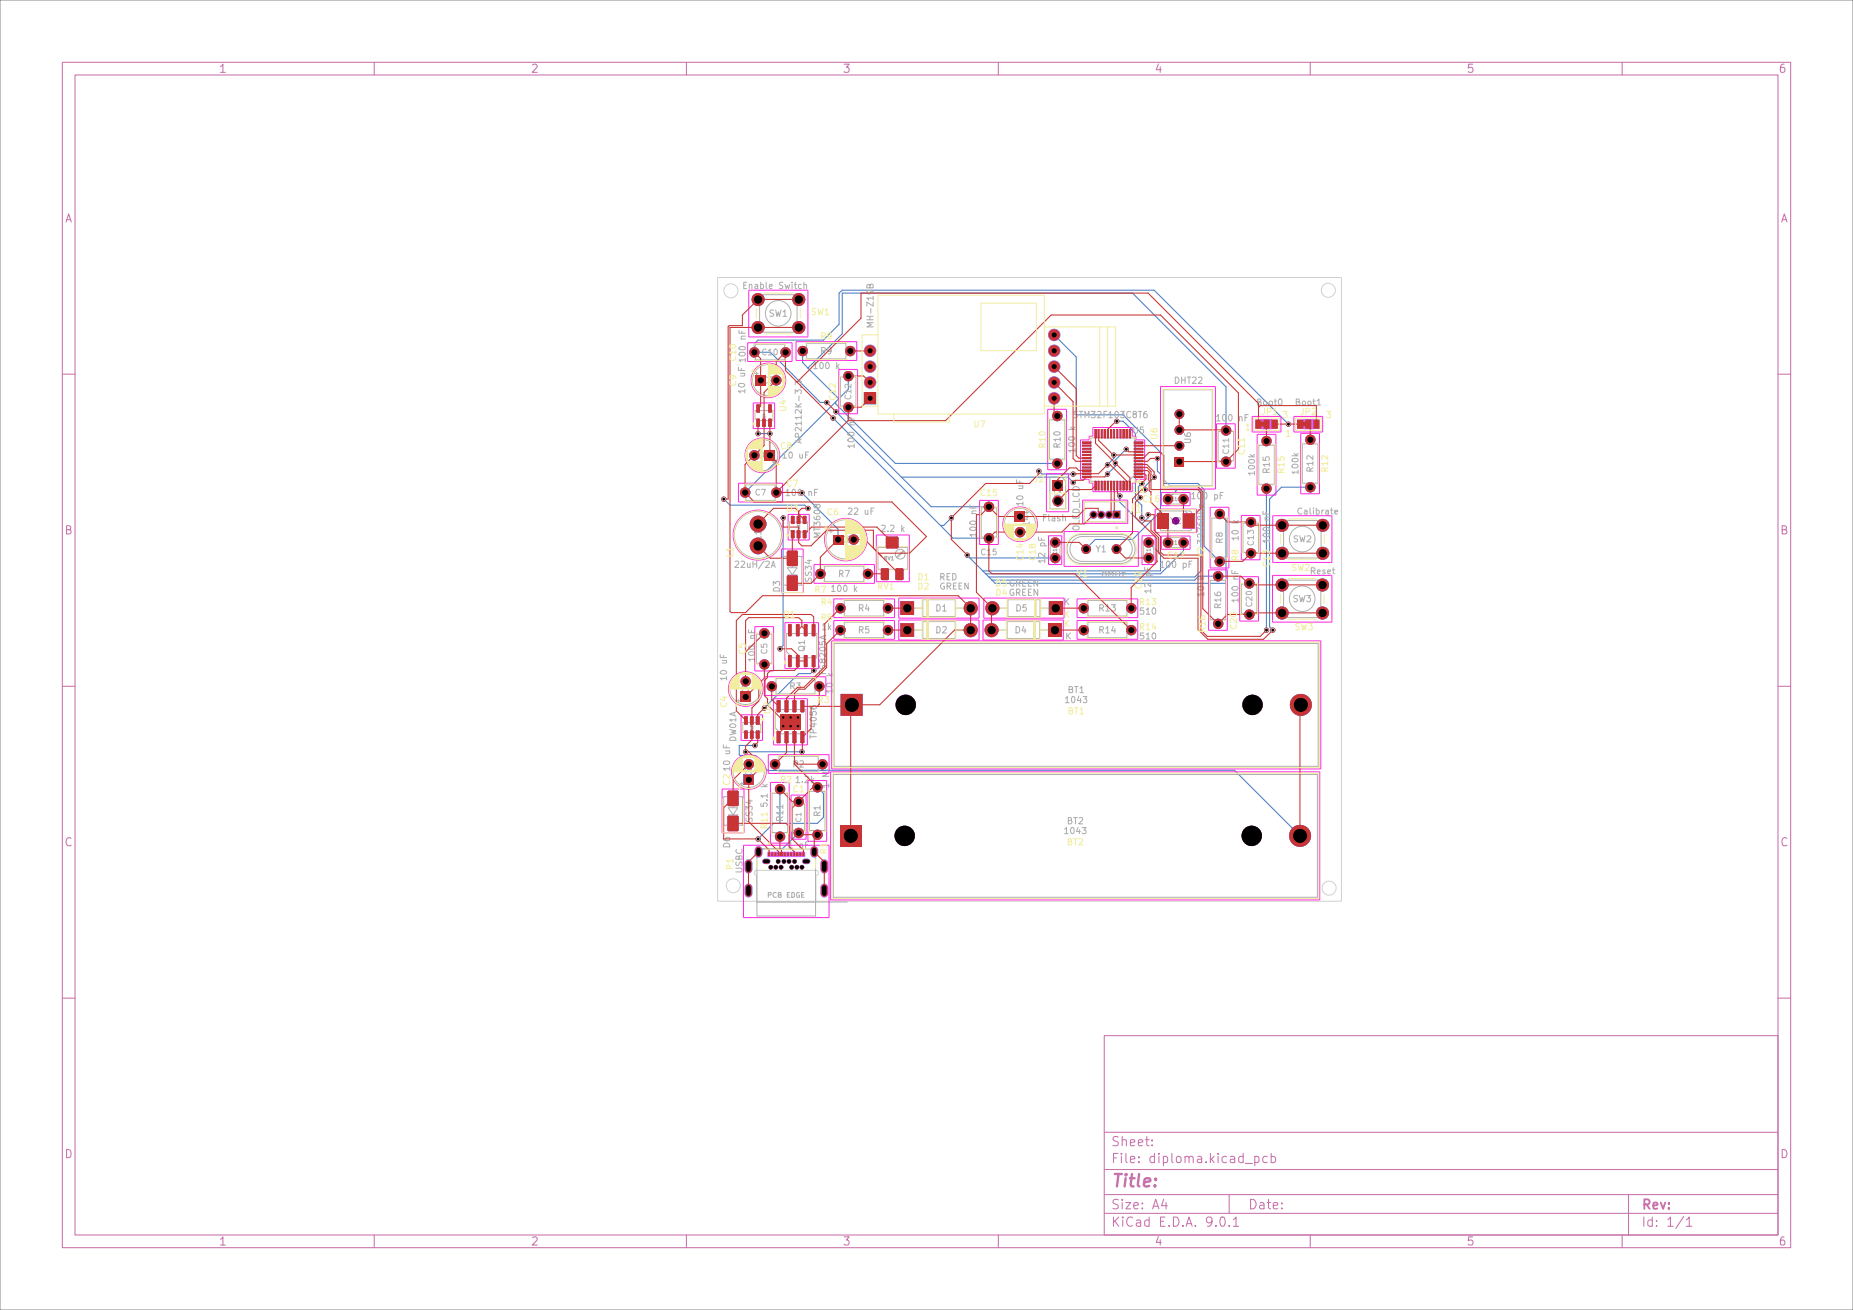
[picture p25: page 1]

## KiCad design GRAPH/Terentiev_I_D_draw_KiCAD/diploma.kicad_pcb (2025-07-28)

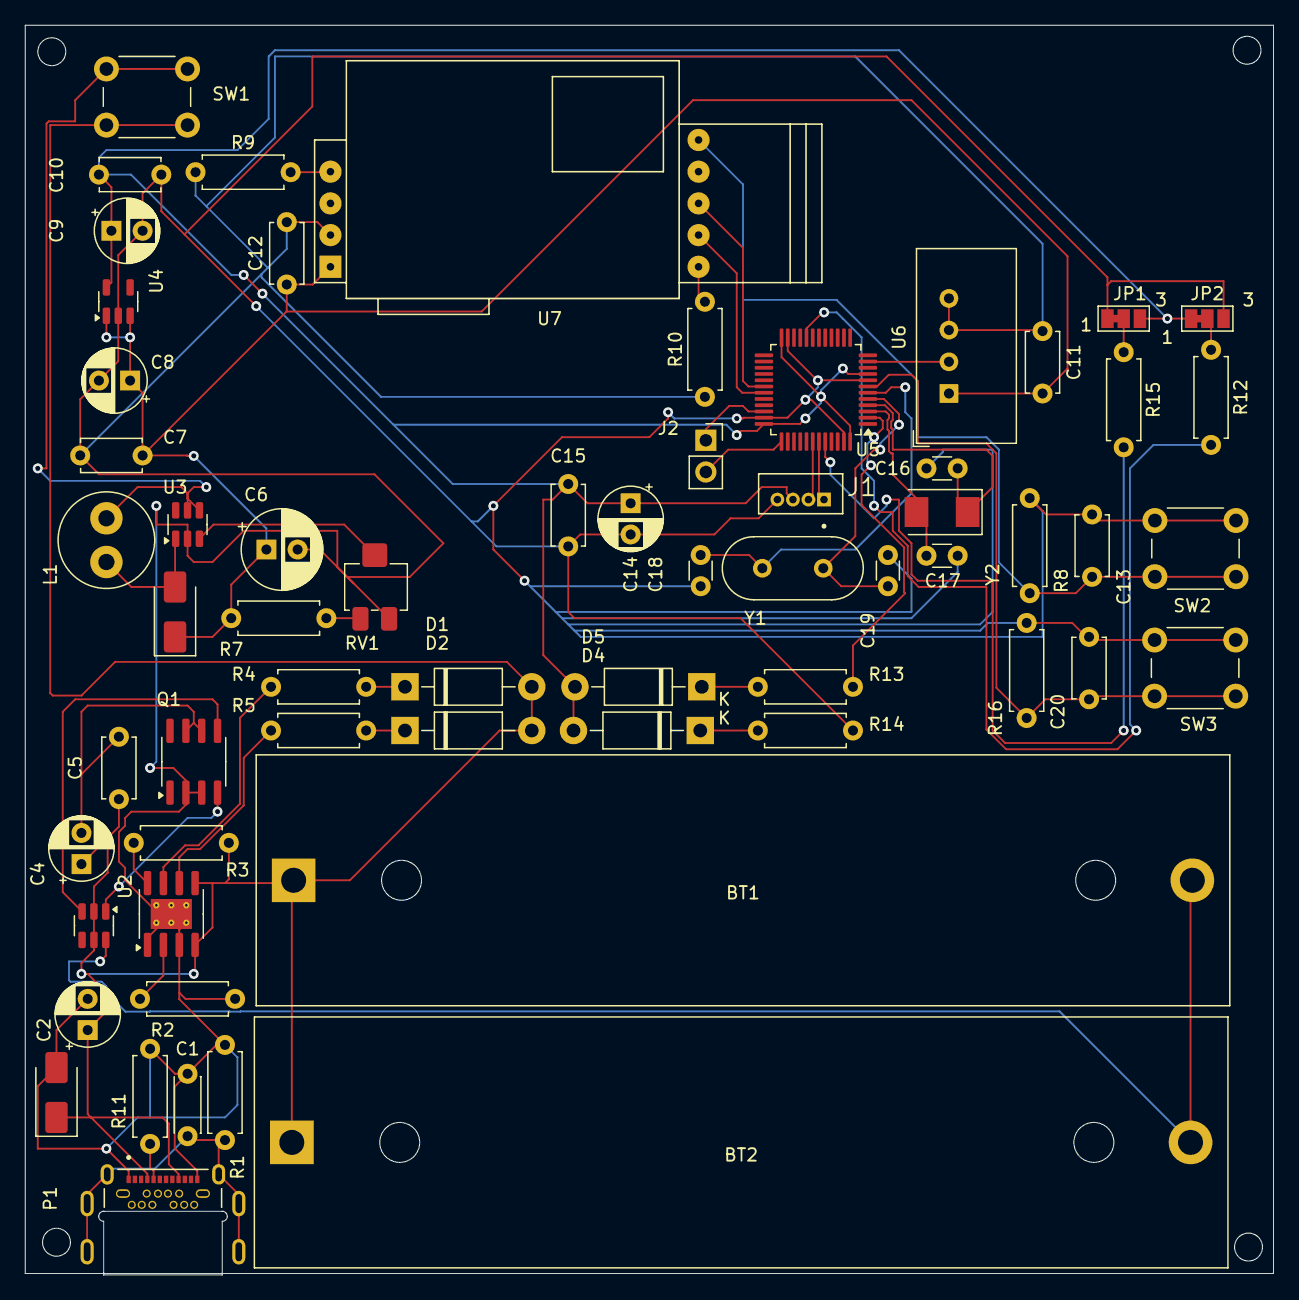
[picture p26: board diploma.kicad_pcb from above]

Board: 2 copper layers, 100.0 x 100.0 mm, 62 parts (0 on the bottom side), 42 nets.

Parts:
BT1, BT2: 1043; BatteryHolder_MPD_BH-18650-PC2
C1: 1 nF; C_Disc_D4.3mm_W1.9mm_P5.00mm
C2, C4, C8, C9, C14: 10 uF; CP_Radial_D5.0mm_P2.50mm
C5, C7, C10, C11, C12, C13, C15, C20: 100 nF; C_Disc_D4.7mm_W2.5mm_P5.00mm
C6: 22 uF; CP_Radial_D6.3mm_P2.50mm
C16, C17: 100 pF; C_Disc_D3.0mm_W1.6mm_P2.50mm
C18, C19: 12 pF; C_Disc_D3.0mm_W1.6mm_P2.50mm
D1: RED; D_DO-41_SOD81_P10.16mm_Horizontal
D2, D4, D5: GREEN; D_DO-41_SOD81_P10.16mm_Horizontal
D3, D6: SS34; D_SMA
J1: OLED_LCD; TE_1734598-4
J2: Flash; PinSocket_1x02_P2.54mm_Vertical
JP1: Boot0; SolderJumper-3_P1.3mm_Bridged12_Pad1.0x1.5mm_NumberLabels
JP2: Boot1; SolderJumper-3_P1.3mm_Bridged12_Pad1.0x1.5mm_NumberLabels
L1: 22uH/2A; L_Radial_D7.5mm_P3.50mm_Fastron_07P
P1: USBC; usbc
Q1: FS8205A; SOIC-8_3.9x4.9mm_P1.27mm
R1: 1 M; R_Axial_DIN0207_L6.3mm_D2.5mm_P7.62mm_Horizontal
R2: 1.2k; R_Axial_DIN0207_L6.3mm_D2.5mm_P7.62mm_Horizontal
R3, R8, R16: 10 k; R_Axial_DIN0207_L6.3mm_D2.5mm_P7.62mm_Horizontal
R4, R5: 1k; R_Axial_DIN0207_L6.3mm_D2.5mm_P7.62mm_Horizontal
R7, R9, R10: 100 k; R_Axial_DIN0207_L6.3mm_D2.5mm_P7.62mm_Horizontal
R11: 5.1 k; R_Axial_DIN0207_L6.3mm_D2.5mm_P7.62mm_Horizontal
R12, R15: 100k; R_Axial_DIN0207_L6.3mm_D2.5mm_P7.62mm_Horizontal
R13, R14: 510; R_Axial_DIN0207_L6.3mm_D2.5mm_P7.62mm_Horizontal
RV1: 2.2 k; Potentiometer_Bourns_3214X_Vertical
SW1: Enable Switch; SW_PUSH_6mm
SW2: Calibrate; SW_PUSH_6mm
SW3: Reset; SW_PUSH_6mm
U1: TP4056; SOIC-8-1EP_3.9x4.9mm_P1.27mm_EP2.41x3.3mm_ThermalVias
U2: DW01A; SOT-23-6
U3: MT3608; SOT-23-6
U4: AP2112K-3.3; SOT-23-5
U5: STM32F103C8T6; LQFP-48_7x7mm_P0.5mm
U6: DHT22; ASAIR_AM2302_P2.54mm_Vertical
U7: MH-Z19B
Y1: 8MHz; Crystal_HC49-U_Vertical
Y2: 32768Hz; Crystal_SMD_Abracon_ABM3-2Pin_5.0x3.2mm

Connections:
+3.3V: C9.1, C10.1, C14.1, C15.1, D4.2 (A), D5.2 (A), J1.3, JP1.3 (B), JP2.1 (A), U4.5 (VOUT), U5.9 (VDDA), U5.24 (VDD), U5.36 (VDD), U5.48 (VDD)
+5V: C6.1, C7.1, C8.1, C11.2, C12.1, D3.1 (K), R7.1, U4.1 (VIN), U4.3 (EN), U6.1 (VDD), U7.VIN
GND: C1.2, C2.2, C6.2, C7.2, C8.2, C9.2, C10.2, C11.1, C12.2, C13.2, C14.2, C15.2, C16.1, C17.1, C18.2, C19.2, C20.2, D6.2 (A), J1.4, JP1.1 (A), JP2.3 (B), P1.A1 (GND_A), P1.A12 (GND_A), Q1.2, Q1.3, R1.2, R2.2, R8.2, R9.1, R10.1, R11.2, R14.1, R16.1, RV1.3, SW2.2, SW3.2, U1.1 (TEMP), U1.3 (GND), U1.9 (EPAD), U3.2 (GND), U4.2 (GND), U5.8 (VSSA), U5.23 (VSS), U5.35 (VSS), U5.47 (VSS), U6.3 (GND), U6.4 (GND), U7.GND
unnamed: C1.1, P1.SH1 (SHIELD), P1.SH2 (SHIELD), P1.SH3 (SHIELD), P1.SH4 (SHIELD), P1.SH5 (SHIELD), P1.SH6 (SHIELD), R1.1
unnamed: C4.2, C5.2, Q1.6, Q1.7
unnamed: C13.1, R8.1, SW2.1, U7.HD
unnamed: BT1.1, BT2.1, C2.1, C4.1, C5.1, D1.2 (A), D2.2 (A), D6.1 (K), P1.A4 (VBUS_A), P1.A9 (VBUS_A), R3.1, SW1.1 (A), U1.4 (V_{CC}), U1.5 (BAT), U2.2 (CS), U2.5 (VCC)
unnamed: D1.1 (K), R4.1
unnamed: D2.1 (K), R5.2
unnamed: D3.2 (A), L1.2, U3.1 (SW)
unnamed: D4.1 (K), R14.2
unnamed: D5.1 (K), R13.2
unnamed: J1.1, U5.43 (PB7)
unnamed: J1.2, U5.42 (PB6)
unnamed: J2.1, U5.34 (PA13)
unnamed: J2.2, U5.37 (PA14)
unnamed: JP1.2 (C), R15.1
unnamed: JP2.2 (C), R12.1
unnamed: P1.A5 (CC1), R11.1
unnamed: R7.2, RV1.1
unnamed: R9.2, U7.PWM
unnamed: R10.2, U7.VO
unnamed: L1.1, SW1.2 (B), U3.4 (EN), U3.5 (IN)
unnamed: R3.2, U1.8 (CE)
unnamed: R2.1, U1.2 (PROG)
unnamed: R4.2, U1.7 (~CHRG)
unnamed: R5.1, U1.6 (~STDBY)
unnamed: BT1.2, BT2.2, U2.6 (GND)
unnamed: Q1.5, U2.3 (OC)
unnamed: Q1.4, U2.1 (OD)
unnamed: RV1.2, U3.3 (FB)
unnamed: R15.2, U5.44 (BOOT0)
unnamed: C20.1, R16.2, SW3.1, U5.7 (NRST)
unnamed: U5.11 (PA1), U6.2 (SDA)
unnamed: U5.30 (PA9), U7.TX
unnamed: U5.31 (PA10), U7.RX
unnamed: R12.2, U5.20 (PB2)
unnamed: R13.1, U5.2 (PC13)
unnamed: C17.2, U5.3 (PC14), Y2.2
unnamed: C16.2, U5.4 (PC15), Y2.1
unnamed: C19.1, U5.5 (PD0), Y1.2
unnamed: C18.1, U5.6 (PD1), Y1.1

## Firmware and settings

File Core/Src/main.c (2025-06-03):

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
/* Includes ------------------------------------------------------------------*/
#include "main.h"

/* USER CODE BEGIN Includes */
#include "DHT.h"
#include "ssd1306.h"
#include "fonts.h"
#include <stdio.h>
#include <stdbool.h>

/* USER CODE END Includes */

/* USER CODE BEGIN PD */
#define BASE_UPDATE 250
#define DHT_ERROR_DELAY 10000 / BASE_UPDATE
#define CO2_ERROR_DELAY 10000 / BASE_UPDATE
#define CO2_HEATING 3 * 60 * 1000 / BASE_UPDATE
/* USER CODE END PD */

I2C_HandleTypeDef hi2c1;

UART_HandleTypeDef huart1;

void SystemClock_Config(void);
static void MX_GPIO_Init(void);
static void MX_I2C1_Init(void);
static void MX_USART1_UART_Init(void);
/* USER CODE BEGIN 0 */
#define MHZ19B_UART &huart1
int MHZ19B_GetCO2() {
	uint8_t response[9];
	uint8_t cmd_get_co2[] = { 0xFF, 0x01, 0x86, 0x00, 0x00, 0x00, 0x00, 0x00, 0x79 };
	HAL_StatusTypeDef tx = HAL_UART_Transmit(MHZ19B_UART, cmd_get_co2, sizeof(cmd_get_co2), 100);
	HAL_StatusTypeDef rx = HAL_UART_Receive(MHZ19B_UART, response, 9, 100);
    if (tx == HAL_OK && rx == HAL_OK) {
        uint16_t co2 = (response[2] << 8) | response[3];
        uint8_t checksum = 0;
        for(int i = 1; i < 8; i++)
                checksum += response[i];
    	checksum = 0xff - checksum;
    	checksum++;
    	if(checksum == response[8])
    		return co2;
    	else
    		return -1;
    }
    return -1;
}


/* USER CODE END 0 */

/**
  * @brief  The application entry point.
  * @retval int
  */
int main(void)
{

  /* MCU Configuration--------------------------------------------------------*/

  /* Reset of all peripherals, Initializes the Flash interface and the Systick. */
  HAL_Init();

  /* Configure the system clock */
  SystemClock_Config();

  /* Initialize all configured peripherals */
  MX_GPIO_Init();
  MX_I2C1_Init();
  MX_USART1_UART_Init();
  /* USER CODE BEGIN 2 */

  static DHT_sensor bedRoom = {GPIOA, GPIO_PIN_1, DHT22, GPIO_PULLUP};
  int co2 = -1;
  DHT_data d =  {-128.0f,-128.0f};
  int dht_error = 0;
  int co2_error = 0;
  char buf[120];
  SSD1306_Init ();

  /* USER CODE END 2 */

  /* Infinite loop */
  /* USER CODE BEGIN WHILE */
  bool got_co2_error = false;
  bool got_dht_error = false;
  bool needs_refresh = false;
  int heating_co2 = 0;
  while (1)
  {
	    SSD1306_GotoXY (10,7);
	    if(dht_error >= DHT_ERROR_DELAY) {
	    	if(got_dht_error == false){
	    		got_dht_error = true;
	    		needs_refresh = true;
	    	}
	    	sprintf(buf, "  DHT22 Error          ");
	    	SSD1306_Puts (buf, &Font_7x10, 1);
	    }
	    else
	    {
	    	d = DHT_getData(&bedRoom);
			if(d.temp > -128.0f || d.hum > -128.0f) {
				sprintf(buf, "| %-2.1fC  %2.1f%% |      ",
						d.temp, d.hum);
				dht_error = 0;
				SSD1306_Puts (buf, &Font_7x10, 1);
			}
			else
				dht_error++;
	    }
	    SSD1306_GotoXY (10,18);
	    if(heating_co2 == CO2_HEATING){
			if(co2_error >= CO2_ERROR_DELAY){
				if(got_co2_error == false){
					got_co2_error = true;
					needs_refresh = true;
				}
				sprintf(buf, "  MHZ19 Error        ");
				SSD1306_Puts (buf, &Font_7x10, 1);
			}
			else{
				co2 = MHZ19B_GetCO2();
				if(co2 != -1){
					sprintf(buf, "| CO2  %-4dppm |    ", co2);
					co2_error = 0;
					SSD1306_Puts (buf, &Font_7x10, 1);
				}
				else
					co2_error++;
			}
	    }
	    else
	    {
	    	co2 = MHZ19B_GetCO2();
			sprintf(buf, "CO2 wait %-3dsec.        ",
					(CO2_HEATING-heating_co2)*BASE_UPDATE/1000);
			SSD1306_Puts (buf, &Font_7x10, 1);
	    	heating_co2++;
	    	if(heating_co2 == CO2_HEATING)
	    		needs_refresh = true;
	    }
	    if (needs_refresh){
	    	SSD1306_Fill(SSD1306_COLOR_BLACK);
	    	needs_refresh = false;
	    }
	    SSD1306_UpdateScreen();
	    HAL_Delay(BASE_UPDATE);
    /* USER CODE END WHILE */

    /* USER CODE BEGIN 3 */
  }
  /* USER CODE END 3 */
}

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


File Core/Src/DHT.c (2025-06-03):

#include "DHT.h"

#define lineDown() 		HAL_GPIO_WritePin(sensor->DHT_Port, sensor->DHT_Pin, GPIO_PIN_RESET)
#define lineUp()		HAL_GPIO_WritePin(sensor->DHT_Port, sensor->DHT_Pin, GPIO_PIN_SET)
#define getLine()		(HAL_GPIO_ReadPin(sensor->DHT_Port, sensor->DHT_Pin) == GPIO_PIN_SET)
#define Delay(d)		HAL_Delay(d)

static void goToOutput(DHT_sensor *sensor) {
	GPIO_InitTypeDef GPIO_InitStruct = {0};
  lineUp();
  GPIO_InitStruct.Pin = sensor->DHT_Pin;
  GPIO_InitStruct.Mode = GPIO_MODE_OUTPUT_OD;
  GPIO_InitStruct.Pull = sensor->pullUp;
  GPIO_InitStruct.Speed = GPIO_SPEED_FREQ_HIGH;
  HAL_GPIO_Init(sensor->DHT_Port, &GPIO_InitStruct);
}

static void goToInput(DHT_sensor *sensor) {
  GPIO_InitTypeDef GPIO_InitStruct = {0};
  GPIO_InitStruct.Pin = sensor->DHT_Pin;
  GPIO_InitStruct.Mode = GPIO_MODE_INPUT;
  GPIO_InitStruct.Pull = sensor->pullUp;
  HAL_GPIO_Init(sensor->DHT_Port, &GPIO_InitStruct);
}

DHT_data DHT_getData(DHT_sensor *sensor) {
	DHT_data data = {-128.0f, -128.0f};
	
	#if DHT_POLLING_CONTROL == 1
	uint16_t pollingInterval;
	if (sensor->type == DHT11) {
		pollingInterval = DHT_POLLING_INTERVAL_DHT11;
	} else {
		pollingInterval = DHT_POLLING_INTERVAL_DHT22;
	}

	if ((HAL_GetTick() - sensor->lastPollingTime < pollingInterval) && sensor->lastPollingTime != 0) {
		data.hum = sensor->lastHum;
		data.temp = sensor->lastTemp;
		return data;
	}
	sensor->lastPollingTime = HAL_GetTick()+1;
	#endif
	goToOutput(sensor);
	lineDown();
	Delay(18);
	lineUp();
	goToInput(sensor);


	#ifdef DHT_IRQ_CONTROL
	__disable_irq();
	#endif
	uint16_t timeout = 0;
	while(getLine()) {
		timeout++;
		if (timeout > DHT_TIMEOUT) {
			#ifdef DHT_IRQ_CONTROL
			__enable_irq();
			#endif
			sensor->lastHum = -128.0f;
			sensor->lastTemp = -128.0f;

			return data;
		}
	}
	timeout = 0;
	while(!getLine()) {
		timeout++;
		if (timeout > DHT_TIMEOUT) {
			#ifdef DHT_IRQ_CONTROL
			__enable_irq();
			#endif
			sensor->lastHum = -128.0f;
			sensor->lastTemp = -128.0f;

			return data;
		}
	}
	timeout = 0;
	while(getLine()) {
		timeout++;
		if (timeout > DHT_TIMEOUT) {
			#ifdef DHT_IRQ_CONTROL
			__enable_irq();
			#endif
			return data;
		}
	}
	
	uint8_t rawData[5] = {0,0,0,0,0};
	for(uint8_t a = 0; a < 5; a++) {
		for(uint8_t b = 7; b != 255; b--) {
			uint16_t hT = 0, lT = 0;
			while(!getLine() && lT != 65535) lT++;
			timeout = 0;
			while(getLine()&& hT != 65535) hT++;
			if(hT > lT) rawData[a] |= (1<<b);
		}
	}

    #ifdef DHT_IRQ_CONTROL
	__enable_irq();
    #endif

	if((uint8_t)(rawData[0] + rawData[1] + rawData[2] + rawData[3]) == rawData[4]) {
		if (sensor->type == DHT22) {
			data.hum = (float)(((uint16_t)rawData[0]<<8) | rawData[1])*0.1f;
			if(!(rawData[2] & (1<<7))) {
				data.temp = (float)(((uint16_t)rawData[2]<<8) | rawData[3])*0.1f;
			}	else {
				rawData[2] &= ~(1<<7);
				data.temp = (float)(((uint16_t)rawData[2]<<8) | rawData[3])*-0.1f;
			}
		}
		if (sensor->type == DHT11) {
			data.hum = (float)rawData[0];
			data.temp = (float)rawData[2];
		}
	}
	
	#if DHT_POLLING_CONTROL == 1
	sensor->lastHum = data.hum;
	sensor->lastTemp = data.temp;
	#endif

	return data;	
}

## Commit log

2025-06-03 Limit I2C multi-write count
2025-06-03 Fix checksum variable type
    [main.c]
2025-06-03 Add gitignore and remove generated files
    [test Debug.cfg]

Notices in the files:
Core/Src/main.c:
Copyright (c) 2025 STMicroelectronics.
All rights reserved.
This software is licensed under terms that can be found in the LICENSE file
